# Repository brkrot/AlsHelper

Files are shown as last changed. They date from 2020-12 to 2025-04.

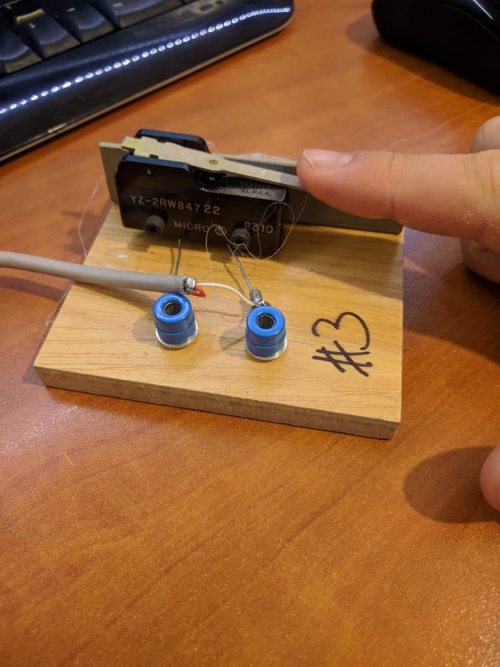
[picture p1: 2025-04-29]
Documents/צילומי מערכת/חיישן מורס.jpeg

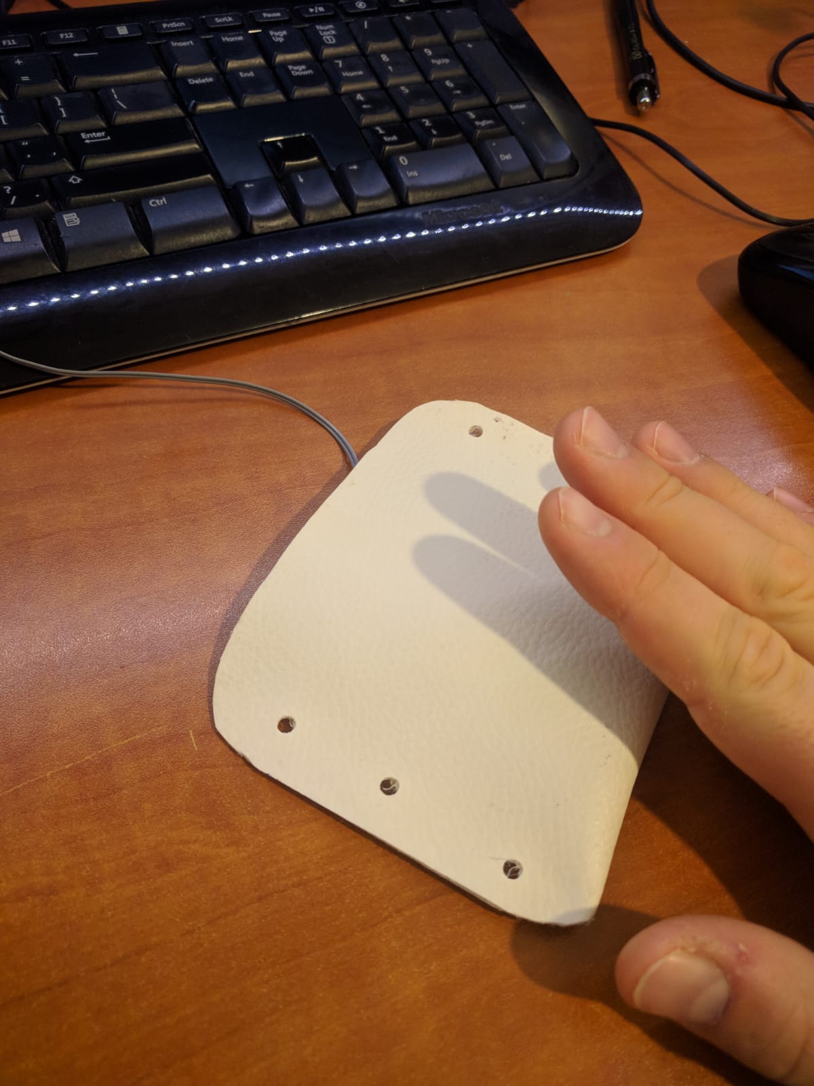
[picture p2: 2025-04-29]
Documents/צילומי מערכת/חיישן כפתור לחיצה רכה 2.jpeg

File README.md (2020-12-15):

# Milbat Project



1.	תקציר
פרויקט זה עוסק ביצירת פתרונות להקלה בחיי היומיום של בעלי מוגבלויות פיזיולוגיות באמצעות עזרים טכנולוגיים.
הרעיון של הפרויקט נובע מרצון משותף להציע פתרונות מסוג זה בשיתוף עם עמותת "מילב"ת" המתעסקת ללא מטרת רווח בסיוע טכנולוגי לאותו קהל.
במהלך הפרויקט פתחנו שתי מערכות:

•	מערכת ניתוח היכולות הפיזיולוגיות:
מטרתה היא לנתח ולמדוד, בעזרת חיישנים מתאימים, את יכולותיו הפיזיולוגיות של אדם עם מוגבלויות כדי שנוכל, בעזרת חיישנים אלו ליצור ממשק עזר מותאם אישית בעבורו. מערכת זו מופעלת ע"י קלינאית תקשורת של העמותה.
•	מערכת עזר מותאמת אישית:
המערכת מבוססת על מיקרו-מעבד מסוג Arduino. המערכת כוללת את אביזר החישה המתאים ביותר כפי שעלה מהניתוח הפיזיולוגי שבחלק הקודם והיא מותאמת אישית למטופל כך שתענה לצרכיו השונים להפעלת מכשירי IoT(התקני בית חכם) העונים לדרישות האדם עם המוגבלות (למשל הדלקה וכיבוי של מזגן, הדלקה וכיבוי של האור , הזעקת עזרה ע"י לחצן מצוקה וכו' ...)

בנוסף יצרנו גם אפליקציה המתאימה למכשירים מסוג Android שעובדת עם מערכות אלו.
האפליקציה שיצרנו מתממשקת למערכת ניתוח היכולות ועוזרת לנו בחיווי נוח וקל של יכולותיו הפיזיות של המטופל
באפליקציה זו יצרנו גם מחולל מערכת אישית. באמצעות ממשק פשוט ונוח ניתן ליצור קוד תכנותי עבור מערכת העזר, כך שניתן בקלות ליצור מערכת מותאמת אישית לכל מטופל.
בנוסף האפליקציה יכולה לתפקד יחד עם מערכת העזר על מנת לבצע פעולות תקשורתיות כגון שליחת SMS או התקשרות למספר טלפון/פלאפון.
* [ProjectVideos] - User Guide for the app and usage demonstrations
 [ProjectVideos]: https://www.youtube.com/playlist?list=PLXXLm4EyRK1NrguGM9qZ6Np-806uYKIgE

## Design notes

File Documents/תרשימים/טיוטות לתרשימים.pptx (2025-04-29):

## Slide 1

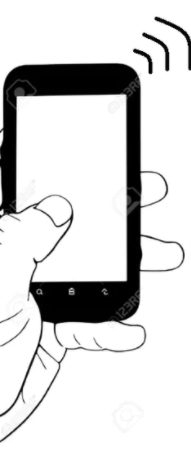
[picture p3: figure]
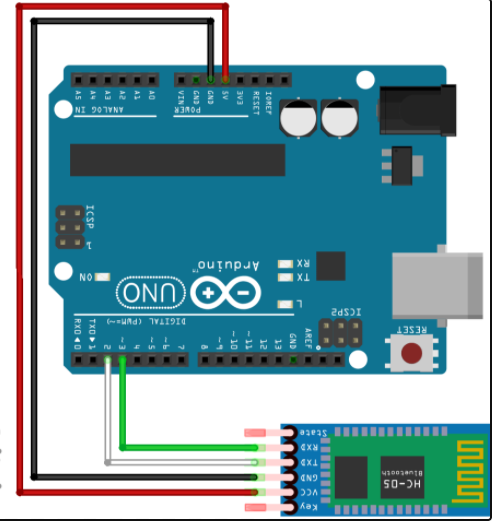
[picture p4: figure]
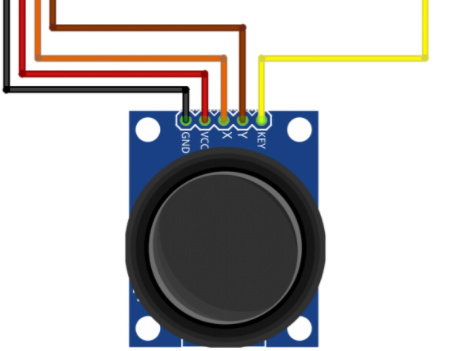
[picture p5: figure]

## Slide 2

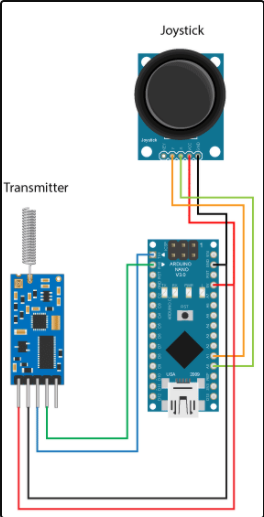
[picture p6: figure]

ג'ויסטיק/*חיישן אחר

צד הארדואינו | ג'ויסטיק/בלוטוס
A1 | VR-y
A0 | VR-x
5V | 5V
GND | GND
Pin3 | RXD
Pin2 | TXD

בלוטוס

אפליקציה

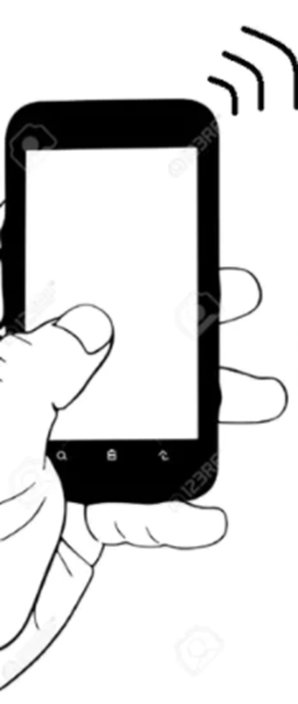
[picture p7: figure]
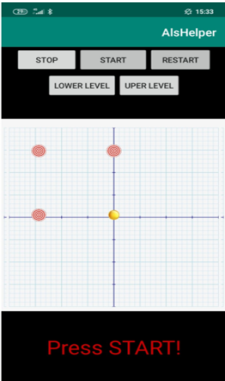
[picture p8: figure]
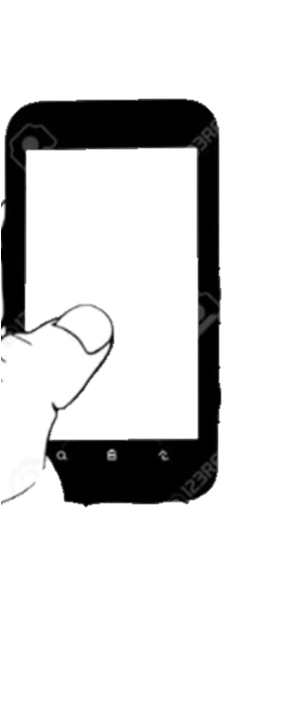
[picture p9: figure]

*זוהי דוגמא לחיבור חיישן בודד – בפועל חיברנו מס' רב של חיישנים כפי שיפורט להלןב

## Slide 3

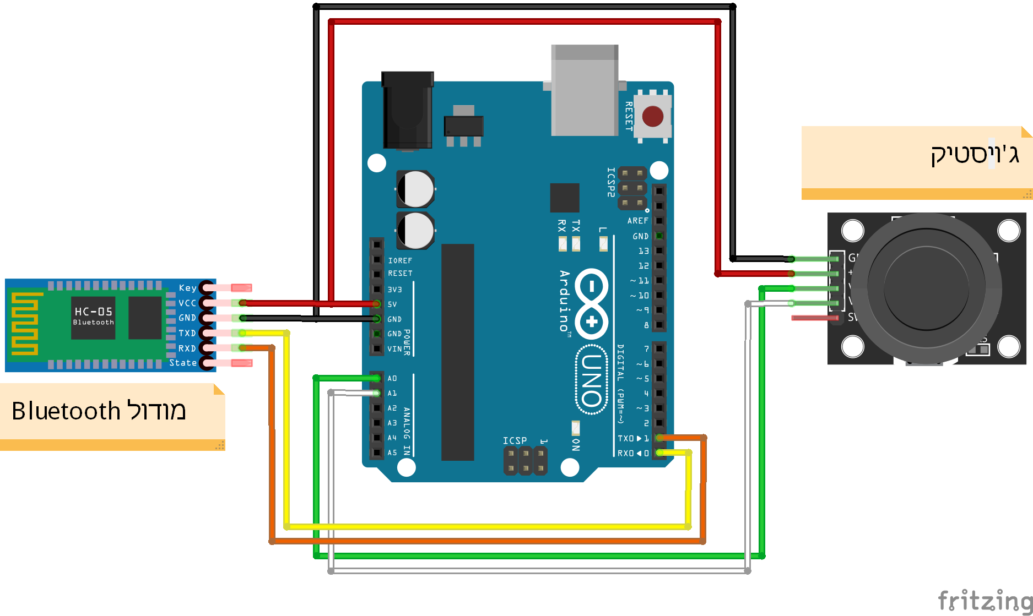
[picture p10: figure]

צבע החוט | החיבור על הלוח | ג'ויסטיק/Bluetooth
לבן | A1 | VR-y
ירוק | A0 | VR-x
אדום | 5V | 5V
שחור | GND | GND
צהוב | Pin1/Tx | RXD
כתום | Pin0/Rx | TXD

זוהי דוגמא לחיבור חיישן בודד – בפועל חיברנו מס' רב של חיישנים כפי שיפורט להלן.

אפליקציה

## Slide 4

מודול Bluetooth המחובר לארדואינו

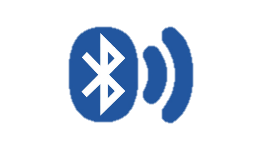
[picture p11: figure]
תוצאת תמונה עבור ‪bluet logo png‬‏

מתאם Bluetooth
במכשיר האנדרואיד

מיקרו בקר-ארדואינו

חיישן

אפליקציית האבחון

"מבחן" עם מסך חיווי

מחולל הקוד

המלצות
לקלינאית

שמירת המידע מן המבחן

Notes: בלוקים מערכת ניתוח

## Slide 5

מחולל הקוד

המלצות
לקלינאית

שמירת המידע מן המבחן

בחירת חיישן ע"פ המלצות

בחירת אופן תפעול החיישן הספציפי

בחירת פעולה עבור כ"א ממצבי החיישן

צריבה על מערכת עזר ריקה/מחודשת

שליחה למחשב

יצירת קובץ עם קוד תכנותי מותאם אישית

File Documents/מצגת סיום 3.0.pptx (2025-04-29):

## פרויקט מילב"ת

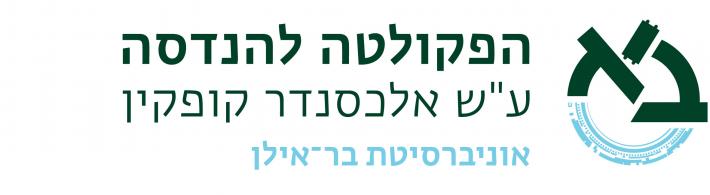
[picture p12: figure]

מערך IoT לאנשים עם מוגבלויות
פרויקט שנה ד'
דבי טברסקי וברק רוט

## הרקע לפרויקט

- קהל היעד – אנשים בעלי מוגבלויות עם אופי שיתוקי
- עמותת מילב"ת
- סיפורים אישיים של מטופלים
- הדרישות לפיתוח מוצר

## חלקי הפרויקט

- חלק 1- מערכת ניתוח היכולות הפיזיולוגיות
- חלק 2- מחולל קוד אישי
- חלק 3 – מערכת העזר

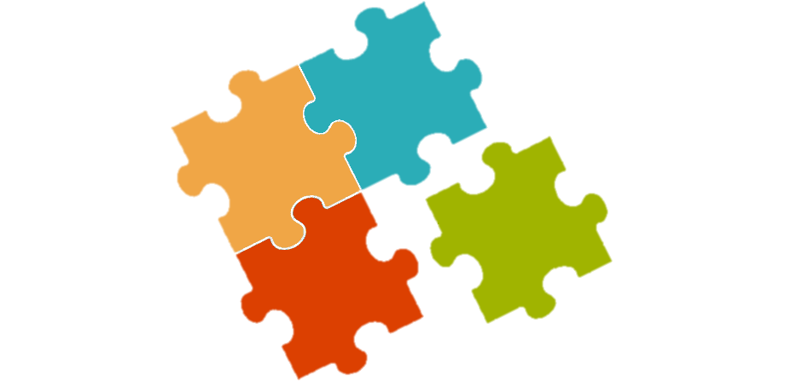
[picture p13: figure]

## הקשר בין המערכות השונות

- בפרויקט זה יש אפליקציה אחת ושני סוגים שונים של מערכות פיזיות.
- האחת, מערכת ניתוח יכולות. יש אחת כזו והיא זו שייכת לעמותת מילב"ת והיא מופעלת ע"י קלינאית התקשורת בזמן ניתוח היכולות.
- הסוג השני הוא מערכת עזר. הרעיון הוא שבעמותה יהיו כ-10 מערכות כאלו כך שבעת הצורך יוכלו בעמותה להתאים את כל המערכת לצרכי המטופל ולתת לו אותה לביתו
- האפליקציה נועדה בעיקר עבור מערכת ניתוח היכולות ובהמשך עבור מחולל הקוד האישי, אך היא רלוונטית גם עבור מערכת העזר.

## אביזרי קלט

- אביזרי הקלט מתחברים למערכת ניתוח יכולות ובהמשך אביזר בודד מחובר למערכת העזר האישית.
כל אביזר קלט מורכב מכמה חלקים:
- חיישן אלקטרוני
- התקן פלסטיק/גומי/אחר לצורך אחיזה נוחה ו/או חיבור על גוף המשתמש.
- חלקים נוספים הגורמים לתגובת החיישן להיות אפקטיבית (למשל מגנט בחיישן גבה)

## חלק 1 מערכת ניתוח יכולות

## חלק 1 - מערכת ניתוח יכולות

- הסבר על מטרת המערכת
- נועדה לתפעול ע"י קלינאית התקשורת של עמותת מילב"ת.
- פיתחנו אפליקציה ייעודית לצורך ניתוח היכולות
- המטופל עובר "מבחנים" בכל סוגי החיישנים.
- חיווי ויזואלי של קלט החיישן על גבי המסך של הפלאפון/ הטאבלט).
- לאחר ה"מבחנים" בכל החיישנים, האפליקציה תיתן את תוצאות המבחנים עבור כל חיישן.

## חלק 1 - מערכת ניתוח יכולות

מבנה כללי של המערכת

חיישן 3

חיישן 1

חיישן 2

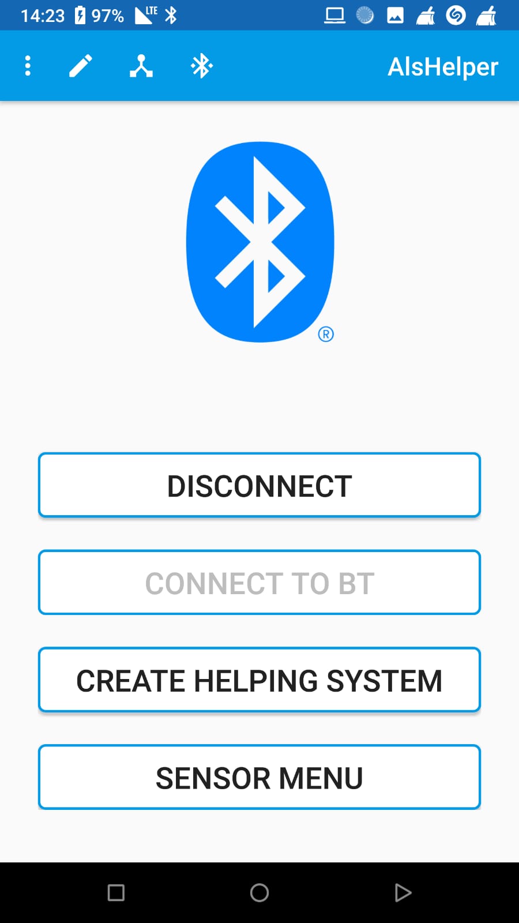
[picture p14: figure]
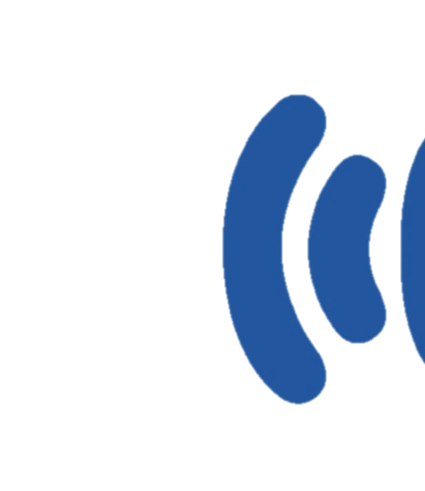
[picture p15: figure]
תוצאת תמונה עבור ‪bluet logo png‬‏
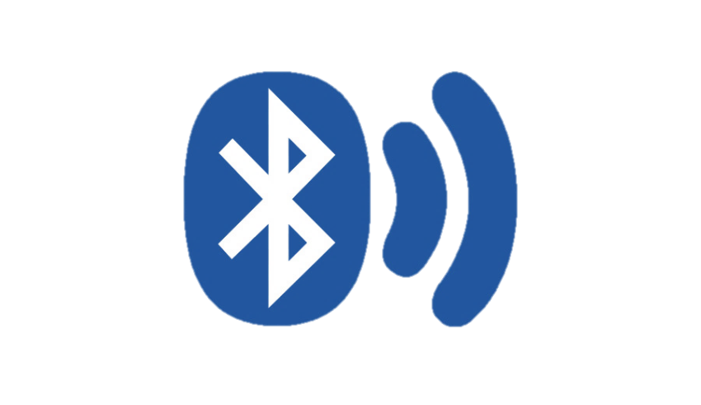
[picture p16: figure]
תוצאת תמונה עבור ‪bluet logo png‬‏
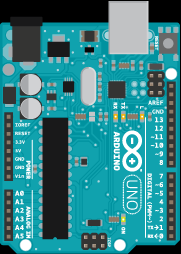
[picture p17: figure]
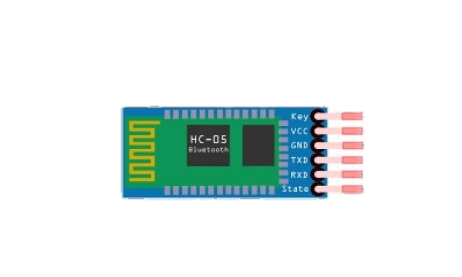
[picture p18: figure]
תוצאת תמונה עבור ‪hc 05 bluetooth clipart png‬‏

## חלק 1 - מערכת ניתוח יכולות

דיאגרמה תהליכית

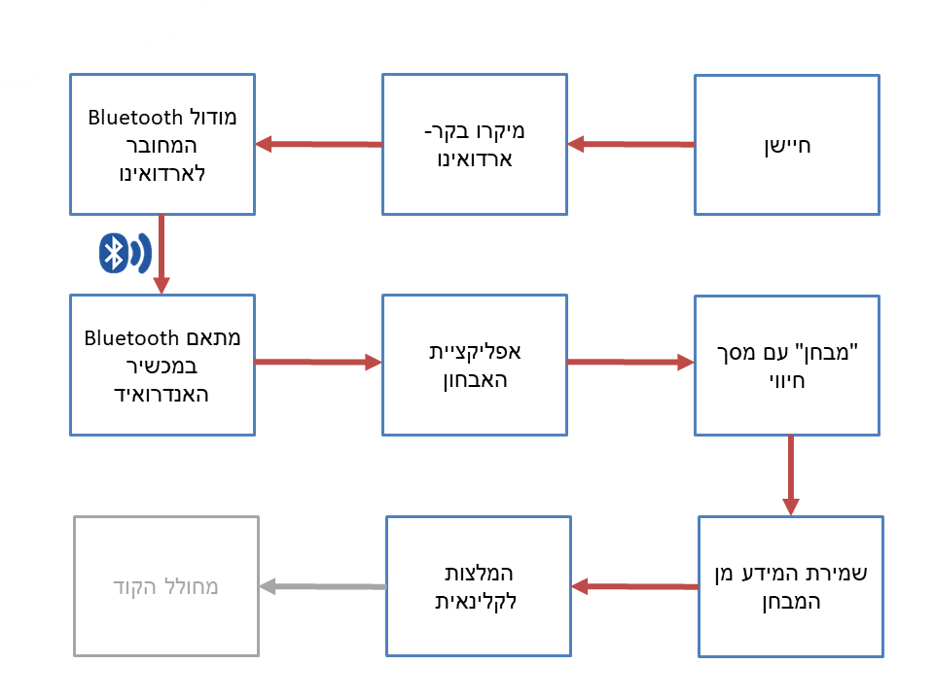
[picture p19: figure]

## סרטוני הדרכה לאפליקציה

לחץ על הסמל למעבר לסרטוני ההדרכה:

חלק 1 - מערכת ניתוח יכולות

## דיאגרמת חיבורים מפורטת - עם ג'ויסטיק

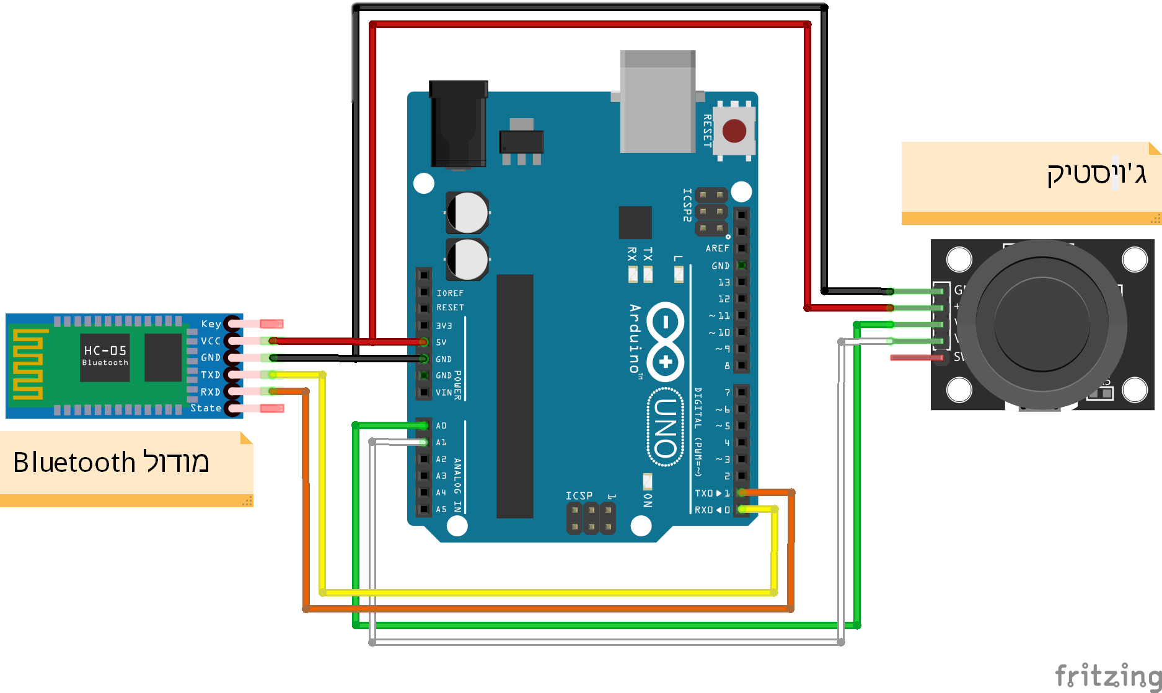
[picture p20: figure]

אפליקציה


צבע החוט | החיבור על הלוח | ג'ויסטיק/Bluetooth
לבן | A1 | VR-y
ירוק | A0 | VR-x
אדום | 5V | 5V
שחור | GND | GND
צהוב | Pin1/Tx | RXD
כתום | Pin0/Rx | TXD

חלק 1 - מערכת ניתוח יכולות

## חלק 2 מחולל קוד אישי

## מחולל קוד אישי

- כדי לגשר בין מערכת הניתוח ובין מערכת העזר יצרנו באפליקציה מחולל קוד אישי.
- בעזרת המחולל ניתן ליצור מערכת מותאמת אישית עבור כל מטופל בצורה פשוטה ונוחה.
- תהליך יצירה פשוט כך שגם מי שאינו מבין במחשבים יוכל ליצור מערכת עבור מטופל

חלק 2 - מחולל קוד אישי

## שלבי הביצוע

- הצגת מסך סיכום התוצאות
- בחירת חיישן ע"פ שיקול הקלינאית בשקלול עם התוצאות
- בחירת פעולות מוצא עבור החיישן
- שליחת הקוד למחשב
- "צריבת" הקוד על גבי מערכת עזר

חלק 2 - מחולל קוד אישי

## דיאגרמה תהליכית של השלבים

חלק 2 - מחולל קוד אישי

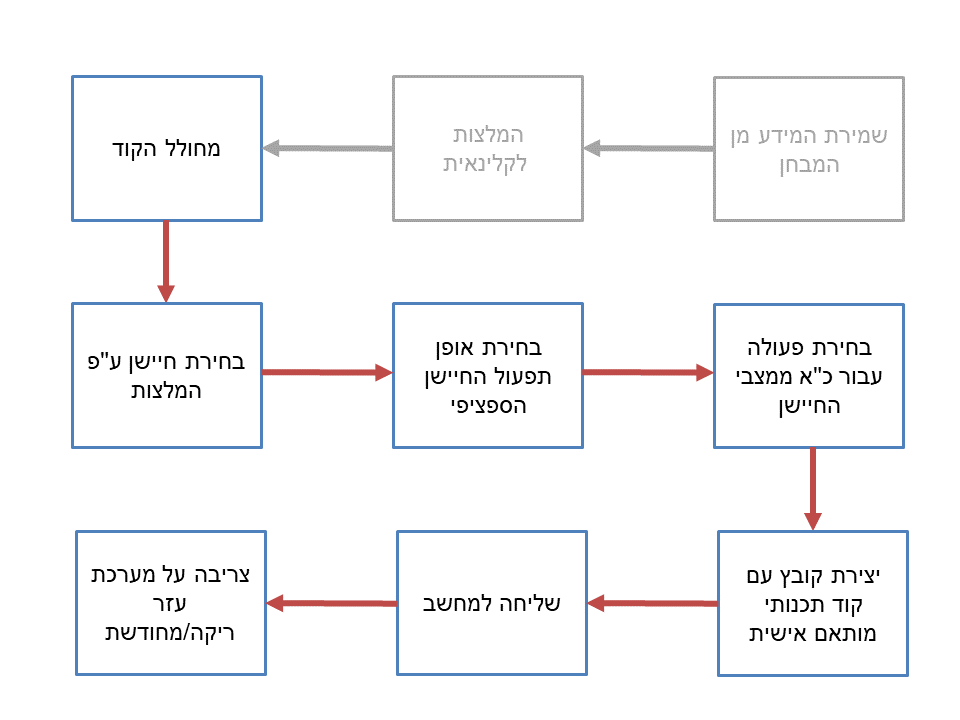
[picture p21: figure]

## סרטוני הדרכה למחולל המערכת האישית

לחץ על הסמל למעבר לסרטוני ההדרכה:

חלק 2 - מחולל קוד אישי

## חלק 3 מערכת העזר האישית

## מערכת העזר האישית

- מערכת עזר מותאמת אישית:
- המערכת מבוססת על מיקרו-מעבד מסוג Arduino.
- המערכת כוללת את אביזר החישה המתאים ביותר כפי שעלה מהניתוח הפיזיולוגי
- מותאמת אישית למטופל כך שתענה לצרכיו השונים
- דוגמאות - מזגן/אור /טלפון/SMS וכו'

חלק 3 - מערכת העזר האישית

## מבנה פשטני של מערכת העזר

חלק 3 - מערכת העזר האישית

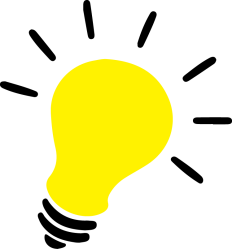
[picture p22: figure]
תוצאת תמונה עבור ‪bulb clipart png‬‏
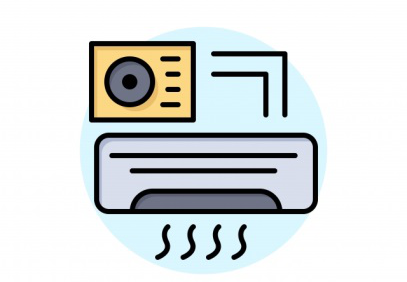
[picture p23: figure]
תוצאת תמונה עבור ‪aircon remote clipart png‬‏
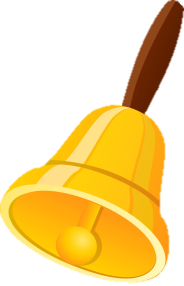
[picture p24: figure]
תוצאת תמונה עבור ‪bell clipart png‬‏

התקן קלט שנבחר בתהליך האבחון

Input

מארז מערכת העזר

Output

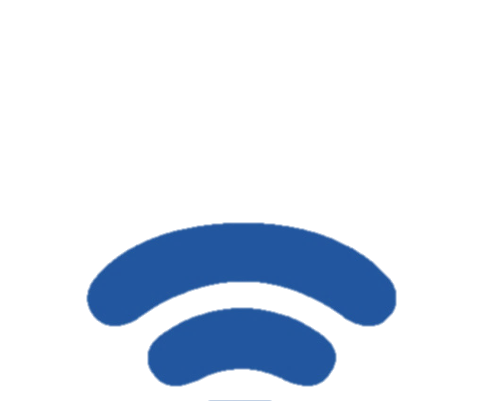
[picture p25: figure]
תוצאת תמונה עבור ‪bluet logo png‬‏

## חיבורים שונים אפשריים לחיישנים

חלק 3 - מערכת העזר האישית

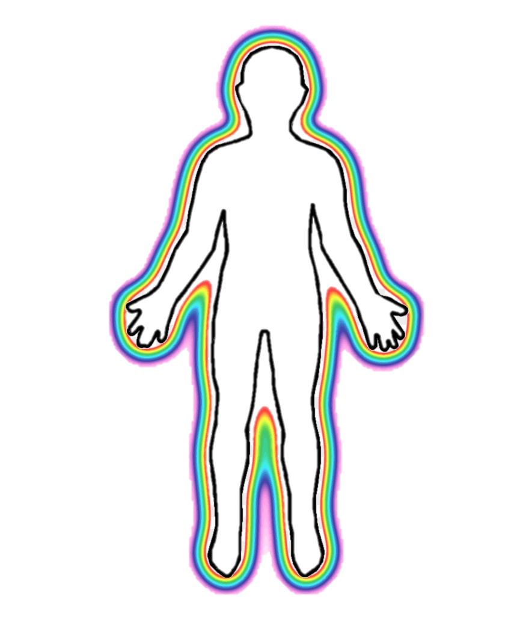
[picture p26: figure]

1

2

תוצאת תמונה עבור ‪aircon remote clipart png‬‏

מארז מערכת העזר

כל הכוכבים מייצגים מקומות בהם ניתן למקם אביזרי קלט-חיישנים

3

4

## דיאגרמת חיבורים מפורטת

חלק 3 - מערכת העזר האישית


מערכת העזר מחולקת לשלושה חלקים.
החלק השחור הוא החלק הנמצא בתוך המארז.
החלק הירוק הוא מתאם התאורה.
החלק האדום הוא החיישן הנבחר, ובמקרה הזה, הג'ויסטיק..

## סרטוני הדרכה למערכת ההתקשרות בעזרת מערכת העזר

לחץ על הסמל למעבר לסרטוני ההדרכה:

חלק 2 - מחולל קוד אישי

Sms Vector SVG Icon - PNG Repo Free PNG Icons
Call PNG Images | Vector and PSD Files | Free Download on Pngtree

## סרטוני הדגמה של תפעול מערכת העזר

לחץ על הסמל למעבר לסרטוני ההדרכה:

חלק 2 - מחולל קוד אישי

## סיכום ומסקנות

- עמדנו בדרישות הפרויקט
- דאגנו לפתח מערכת שנותנת מענה הן מבחינת הקלט והן מבחינת פעולת המוצא לכל אדם עם מוגבלות עם אפשרות התאמה אישית.
- תפעול כלל המערכות הוא קל ונוח וזמין.
יתרונות
- המערכת זולה מבחינה כספית
- ניתן לשדרג אותה יחסית בקלות
חסרונות:
שדרוג צריך להיעשות ע"י מומחה ולא ע"י כל אדם

חלק 2 - מחולל קוד אישי

## פיתוח עתידי

- שיפור בעזרת משוב משתמשים(קלינאית, מטופלים)
- קישוריות טובה יותר לIoT
- מעבר למיקרו בקר מסוג Esp 32
(מהיר יותר, זול יותר, קטן יותר, כולל רכיבי Bluetooth וגם Wi-Fi )
- שדרוג פיזי של המארזים
- שדרוג אפליקציה + הוספת ייעוד:
מערכת אימון - משחק שיחליף את חלק מן ה"מבחנים"

חלק 2 - מחולל קוד אישי

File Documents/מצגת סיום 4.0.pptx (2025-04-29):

## פרויקט מילב"ת


מערך IoT לאנשים עם מוגבלויות
פרויקט שנה ד'
דבי טברסקי וברק רוט
מנחים: ד"ר ססיל יחזקאל, ד"ר אברהם שלי

## הרקע לפרויקט

- קהל היעד – אנשים בעלי מוגבלויות עם אופי שיתוקי
- עמותת מילב"ת
- סיפורים אישיים של מטופלים
- הדרישות לפיתוח מוצר

## חלקי הפרויקט

- חלק 1- מערכת ניתוח היכולות הפיזיולוגיות
- חלק 2- מחולל קוד אישי
- חלק 3 – מערכת העזר


## הקשר בין המערכות השונות

- בפרויקט זה פיתחנו אפליקציה אחת עבור שני סוגים שונים של מערכות פיזיות.
- מערכת ניתוח יכולות. מופעלת ע"י קלינאית התקשורת הנמצאת בעמותת "מילב"ת" לצורך קליטה וניתוח היכולות הפיזית של מטופלים.
- מערכת עזר. הרעיון הוא שבעמותה יהיו כ-10 מערכות כאלו כך שבעת הצורך יוכלו בעמותה להתאים את כל המערכת לצרכי המטופל ולתת לו אותה לביתו
- האפליקציה נועדה בעיקר עבור מערכת ניתוח היכולות ובהמשך עבור מחולל הקוד האישי, אך היא רלוונטית גם עבור מערכת העזר.

## אביזרי קלט

- אביזרי הקלט מתחברים למערכת ניתוח יכולות ובהמשך אביזר בודד מחובר למערכת העזר האישית.
כל אביזר קלט מורכב מכמה חלקים:
- חיישן אלקטרוני
- התקן פלסטיק/גומי/אחר לצורך אחיזה נוחה ו/או חיבור על גוף המשתמש.
- חלקים נוספים הגורמים לתגובת החיישן להיות אפקטיבית (למשל מגנט בחיישן גבה)


## חלק 1 מערכת ניתוח יכולות

## חלק 1 - מערכת ניתוח יכולות

- הסבר על מטרת המערכת
- נועדה לתפעול ע"י קלינאית התקשורת של עמותת מילב"ת.
- פיתחנו אפליקציה ייעודית לצורך ניתוח היכולות
- המטופל עובר "מבחנים" בכל סוגי החיישנים.
- חיווי ויזואלי של קלט החיישן על גבי המסך של הפלאפון/ הטאבלט).
- לאחר ה"מבחנים" בכל החיישנים, האפליקציה תיתן את תוצאות המבחנים עבור כל חיישן.

## חלק 1 - מערכת ניתוח יכולות

מבנה כללי של המערכת

חיישן 3

חיישן 1

חיישן 2


מיקרו בקר + מודול בלוטות'

תוצאת תמונה עבור ‪bluet logo png‬‏
תוצאת תמונה עבור ‪bluet logo png‬‏
תוצאת תמונה עבור ‪hc 05 bluetooth clipart png‬‏

## חלק 1 - מערכת ניתוח יכולות

דיאגרמה תהליכית


## סרטוני הדרכה לאפליקציה

לחץ על הסמל למעבר לסרטוני ההדרכה:

חלק 1 - מערכת ניתוח יכולות

## דיאגרמת חיבורים מפורטת - עם ג'ויסטיק


אפליקציה


צבע החוט | החיבור על הלוח | ג'ויסטיק/Bluetooth
לבן | A1 | VR-y
ירוק | A0 | VR-x
אדום | 5V | 5V
שחור | GND | GND
כתום | Pin1/Tx | RXD
צהוב | Pin0/Rx | TXD

חלק 1 - מערכת ניתוח יכולות

## חלק 2 מחולל קוד אישי

## מחולל קוד אישי

- כדי לגשר בין מערכת הניתוח ובין מערכת העזר יצרנו באפליקציה מחולל קוד אישי.
- בעזרת המחולל ניתן ליצור מערכת מותאמת אישית עבור כל מטופל בצורה פשוטה ונוחה.
- תהליך יצירה פשוט כך שגם מי שאינו מבין במחשבים יוכל ליצור מערכת עבור מטופל

חלק 2 - מחולל קוד אישי

## שלבי הביצוע

- הצגת מסך סיכום התוצאות
- בחירת חיישן ע"פ שיקול הקלינאית בשקלול עם התוצאות
- בחירת פעולות מוצא עבור החיישן
- שליחת הקוד למחשב
- "צריבת" הקוד על גבי מערכת עזר

חלק 2 - מחולל קוד אישי

## דיאגרמה תהליכית של השלבים

חלק 2 - מחולל קוד אישי


## סרטוני הדרכה למחולל המערכת האישית

לחץ על הסמל למעבר לסרטוני ההדרכה:

חלק 2 - מחולל קוד אישי

## חלק 3 מערכת העזר האישית

## מערכת העזר האישית

- מערכת עזר מותאמת אישית:
- המערכת מבוססת על מיקרו-מעבד מסוג Arduino.
- המערכת כוללת את אביזר החישה המתאים ביותר כפי שעלה מהניתוח הפיזיולוגי
- מותאמת אישית למטופל כך שתענה לצרכיו השונים
- דוגמאות - מזגן/אור /טלפון/SMS וכו'

חלק 3 - מערכת העזר האישית

## מבנה פשטני של מערכת העזר

חלק 3 - מערכת העזר האישית

תוצאת תמונה עבור ‪bulb clipart png‬‏
תוצאת תמונה עבור ‪aircon remote clipart png‬‏
תוצאת תמונה עבור ‪bell clipart png‬‏

התקן קלט שנבחר בתהליך האבחון

Input

מארז מערכת העזר

Output

תוצאת תמונה עבור ‪bluet logo png‬‏

## חיבורים שונים אפשריים לחיישנים

חלק 3 - מערכת העזר האישית


1

2

תוצאת תמונה עבור ‪aircon remote clipart png‬‏

מארז מערכת העזר

כל הכוכבים מייצגים מקומות בהם ניתן למקם אביזרי קלט-חיישנים

3

4

## דיאגרמת חיבורים מפורטת

חלק 3 - מערכת העזר האישית


מערכת העזר מחולקת לשלושה חלקים.
החלק השחור הוא החלק הנמצא בתוך המארז.
החלק הירוק הוא מתאם התאורה.
החלק האדום הוא החיישן הנבחר, ובמקרה הזה, הג'ויסטיק..

## סרטוני הדרכה למערכת ההתקשרות בעזרת מערכת העזר

לחץ על הסמל למעבר לסרטוני ההדרכה:

חלק 2 - מחולל קוד אישי

Sms Vector SVG Icon - PNG Repo Free PNG Icons
Call PNG Images | Vector and PSD Files | Free Download on Pngtree

## סרטוני הדגמה של תפעול מערכת העזר

לחץ על הסמל למעבר לסרטוני ההדרכה:

חלק 2 - מחולל קוד אישי

## סיכום ומסקנות

- עמדנו בדרישות הפרויקט
- דאגנו לפתח מערכת שנותנת מענה הן מבחינת הקלט והן מבחינת פעולת המוצא לכל אדם עם מוגבלות עם אפשרות התאמה אישית.
- תפעול כלל המערכות הוא קל ונוח וזמין.
יתרונות
- המערכת זולה מבחינה כספית
- ניתן לשדרג אותה יחסית בקלות
חסרונות:
שדרוג צריך להיעשות ע"י מומחה ולא ע"י כל אדם

חלק 2 - מחולל קוד אישי

## פיתוח עתידי

- שיפור בעזרת משוב משתמשים(קלינאית, מטופלים)
- קישוריות טובה יותר לIoT
- מעבר למיקרו בקר מסוג Esp 32
(מהיר יותר, זול יותר, קטן יותר, כולל רכיבי Bluetooth וגם Wi-Fi )
- שדרוג פיזי של המארזים
- שדרוג אפליקציה + הוספת ייעוד:
מערכת אימון - משחק שיחליף את חלק מן ה"מבחנים"

חלק 2 - מחולל קוד אישי

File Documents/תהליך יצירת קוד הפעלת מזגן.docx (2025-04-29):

1. תחיבורים
  a. לד משדר:

חיבור הטרנזיסטור
2N2222 :


https://en.wikipedia.org/wiki/2N2222

חיבור המעגל המלא יחד עם הטרנזיסטור:


את המתח 5V לקחתי מיציאת 5וולט של הארדואינו ובפעם אחרת לקחתי באופן מאולתר מבית הסוללות ע"י חיבור שני חוטים בקצוות הסוללות (4 סוללות סה"כ יצא לי ~6V)
הנגדים אצלי הם של 220 אום

  b. לד קליטה - BRM:

חיברתי את הלד הקולט ע"פ התרשים הבא:

רגלי הלד:

IR Receiver Stand-Alone Pinout Diagram

אופן החיבור: הכחול בפין מס 11(לא 7)

Arduino IR Remote Receiver - Stand-Alone IR Receiver Wiring Diagram

2. קודי ארדואינו
  a. קריאת אות אינפרא אדום מהשלט:

השתמשתי בספרייה הידועה IRremote
ושם השתמשתי בקובץ - IRrecvDumpV2


כשהפעלתי קובץ זה קיבלתי את הפלט הנ"ל עבור לחיצה בודדת של שלט המזגן(הדלקה על קור ב24 מעלות):

START F:\Documents\Arduino\libraries\IRremote\examples\IRrecvDumpV2\IRrecvDumpV2.ino from Sep 2 2020

Ready to receive IR signals at pin 11

Encoding : NEC

Code : 0x1098D008 (32 bits)

Timing[83]:

+8900, -4400 + 550, - 550 + 550, - 500 + 600, - 500

+ 550, -1600 + 600, - 500 + 550, - 550 + 550, - 500

+ 550, - 550 + 550, -1600 + 550, - 550 + 550, - 500

+ 600, -1600 + 550, -1600 + 550, - 550 + 550, - 500

+ 600, - 500 + 550, -1600 + 550, -1650 + 550, - 500

+ 550, -1600 + 600, - 500 + 550, - 550 + 550, - 500

+ 600, - 500 + 550, - 550 + 550, - 500 + 600, - 500

+ 550, - 550 + 550, -1600 + 550, - 550 + 550, - 500

+ 600, - 500 + 550, - 550 + 550, - 500 + 550, -1650

+ 550, -1600 + 550, - 500 + 600, - 500 + 550, - 550

+ 550, - 500 + 600

Pronto Hex: 0000 006D 002A 0000 0156 00A9 0015 0015 0015 0013 0017 0013 0015 003E 0017 0013 0015 0015 0015 0013 0015 0015 0015 003E 0015 0015 0015 0013 0017 003E 0015 003E 0015 0015 0015 0013 0017 0013 0015 003E 0015 003F 0015 0013 0015 003E 0017 0013 0015 0015 0015 0013 0017 0013 0015 0015 0015 0013 0017 0013 0015 0015 0015 003E 0015 0015 0015 0013 0017 0013 0015 0015 0015 0013 0015 003F 0015 003E 0015 0013 0017 0013 0015 0015 0015 0013 0017 0806

unsigned int rawData[83] = {8900,4400, 550,550, 550,500, 600,500, 550,1600, 600,500, 550,550, 550,500, 550,550, 550,1600, 550,550, 550,500, 600,1600, 550,1600, 550,550, 550,500, 600,500, 550,1600, 550,1650, 550,500, 550,1600, 600,500, 550,550, 550,500, 600,500, 550,550, 550,500, 600,500, 550,550, 550,1600, 550,550, 550,500, 600,500, 550,550, 550,500, 550,1650, 550,1600, 550,500, 600,500, 550,550, 550,500, 600}; // NEC 1098D008

unsigned int data = 0x1098D008;

השורה המודגשת היא מה שמעניין אותנו ואותה הכנסתי לקוד השידור

  b. קוד ארדואינו - שידר האות המוקלט לצורך הפעלת המזגן:

השתמשתי בספרייה הידועה IRremote
ושם השתמשתי בקובץ – IrsendRawDemo

בקובץ זה השתמשתי רק בחלק הראשון ובו הדבקתי את קוד האינפרא אדום

יכולת תכנות – שמירת הקודים בזיכרון:
אני השתמשתי בספרייה שנקרא EEPROM שנותנת גישה אל הזיכרון ויכולת לכתוב שם באופן קבוע גם אחרי ריסט
גודל הזיכרון הוא 1 קילו בייט

הכתיבה היא בשתי צורות
read write שכותבים אל בייט בודד
וput get שהם ככל הנראה חדשים יותר לפי מה שקראתי באחד המקומות והם מאפשרים כתיבה ליותר מבייט אחד (כלומר ניתן לכתוב מספרים בגדול של יותר

מ 255=2^8 .

כתבתי שתי פונקציות שיודעות לקרוא מערך מהזיכרון ולכתוב אחד לזיכרון
יש ספרייה מורחבת שעושה את הדברים האלו אבל העדפתי לממש כי המימוש היה לא ככ מסובך וכמובן תמיד עדיף להבין מה אתה עושה ולא להסתמך..
https://github.com/thijse/Arduino-EEPROMEx זאת הכתובת של הספרייה המורחבת

הקובץ האחרון שכתבתי , זה שהצליח להפעיל אצלי את המזגן זה הקובץ

Aux_system_programmble_AC_v1.0_dirty_code_

זה קובץ שמשלב את כל הקודים שראית במסמך זה
יש שם בעיות ודברים לא פתורים עד הסוף אבל העיקר שהוא עובד.

בעיות שיש כרגע בקוד הנוכחי:

- בלאגן
- יש הרבה פונקציות שנלקחו מהקוד של הרסיבר (הקוד השני במסמך זה)
- לא עובד על כל המזגנים
- ניתן לתכנת פעם אחת, אחר כך זה לא עובד
- הפעלה ארוכה מידי של הקוד כאשר לוחצים ימינה

יש מצב שכדאי לכתוב ממחדש את הקוד הזה בצורה מסודרת

כתבתי אותו מהר כי מיהרתי לצאת ולכן הוא לא מסודר מספיק בעיני

~~משהו חשוב~~
~~בעיקרון אפשר להשתמש בקבצים חיצוניים וכך להפוך את הקוד למודולרי~~
~~למשל~~ ~~–~~ ~~יהיה קוד חיצוני שיהיה אחראי לקלוט את אות המזגן וכך אפשר לעבוד בצורה נוחה ומודולרית יותר~~
~~מוטיבציה נוספת לכך~~ ~~–~~ ~~יש לנו צורך ליצור תוכנת אנדרואיד שכותבת קודי ארדואינו.~~
~~אם נצליח לעבוד עם מספר קבצים יהיה לנו יותר קל להרכיב את הפאזל של הקוד הסופי(דבר איתי אם זה לא מספיק ברור למה הכוונה)~~

יש פה כמה קישורים שעזרו לי:

קישור שמסביר איך להתקין סביבת עבודה לארדואינו בתוך ויזואל סטודיו:

https://maker.pro/arduino/tutorial/how-to-use-visual-studio-for-arduino-development

EEPROM

https://roboticsbackend.com/arduino-store-array-into-eeprom/#Writing_int_array_into_EEPROM

https://roboticsbackend.com/arduino-store-int-into-eeprom/

לינקים כללים למדריכי ארדואינו שהמליצו עליהם בקבוצה בפייסבוק:

אחד מהם זה מדריך לארדואינו והשני זה מדריך לכל האלקטרוניקה שמסביב

https://www.youtube.com/playlist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

https://www.youtube.com/playlist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

עוד קישור שיכול להיות שיהיה רלוונטי לנו, משהו לגבי מזדן תדיראן:

https://pastebin.com/hGS2dp1C?fbclid=IwAR2L-4BS2ILfgeg7TMHHI9Gny1b-RQLmAtBrrW3DvM7_63bSjEvXRS41w5E

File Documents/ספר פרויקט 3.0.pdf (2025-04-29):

בס"ד

# פיתוח מערך IoT לאנשים עם מוגבלויות

### פרויקט שנה ד'

# דבי טברסקי 203528021 ברק רוט 203679725

# מנחים :

# ד"ר ססיל יחזקאל

# דר אברהם שלי

# מנחה אקדמי: ד"ר אדי תימן

# תוכן עניינים

תוכן
תוכן עניינים 2 |
.1 תקציר3 |

### 2. הרקע לפרויקט4 |

2.1. קהל היעד 4 |
2.2. עמותת מילב"ת 5 |
.2.3 סיפור אישי של מטופלים5 |
.2.4 הדרישות לפיתוח מוצר 5 |
.3 שיקולים במענה לצורך 7 |
.3.1 מצבו ההתחלתי של המוצר 7 |
3.2. ההחלטה לגבי סביבת הפיתוח 7 |
.4 לב הפרויקט – הדרך לפתרון8 |
4.1. מערכת ניתוח היכולות 8 |

## .1 תקציר

פרויקט זה עוסק ביצירת פתרונות טכנולוגיים להקלה בחיי היומיום של בעלי מוגבלויות פיזיולוגיות. הפרויקט נעשה בשיתוף עם עמותת "מילב"ת" העוסקת בסיוע ומציאת פתרונות הנדסיים ו/או טכנולוגיים עבור בעלי מוגבלויות אלו )ללא מטרת רווח(.

במהלך הפרויקט פיתחנו שתי מערכות:
- מערכת ניתוח היכולות הפיזיולוגיות: מטרת המערכת היא לנתח ולמדוד, בעזרת חיישנים מתאימים, את יכולת המוטוריקה של המטופל ביחס לחיישנים הקיימים במערכת. בעזרת מידע זה, נוכל ליצור מערכת עזר מותאמת אישית המצריכה יכולות מוטוריות אלו. מערכת זו מופעלת ע"י קלינאית תקשורת של העמותה.
- מערכת עזר מותאמת אישית:
המערכת )מבוססת על מיקרו-מעבד מסוג Arduino )המערכת כוללת את החיישן המתאים ביותר כפי שעלה מהניתוח הפיזיולוגי של המערכת הראשונה. מערכת עזר זו מותאמת אישית למטופל כך שתענה לצרכיו השונים להפעלת מכשירי IoT( התקני בית חכם כגון הדלקה וכיבוי של מזגן, הדלקה וכיבוי של האור , הזעקת עזרה ע"י לחצן מצוקה וכו' ...(

בנוסף יצרנו גם אפליקציה המתאימה למכשירים מסוג Android אפליקציה זו עובדת עם שתי מערכות אלו.
האפליקציה שיצרנו מתממשקת למערכת ניתוח היכולות ועוזרת לנו בחיווי נוח וקל של יכולותיו הפיזיות של המטופל וכן אוספת את המידע מה -"מבחנים".

באפליקציה זו יצרנו גם מחולל קוד )ארדואינו( אישי. באמצעות ממשק פשוט ונוח ניתן ליצור קוד תכנותי עבור מערכת העזר, כך שניתן בקלות ליצור מערכת מותאמת אישית לכל מטופל.

בנוסף האפליקציה משמשת כחלק ממערכת העזר למטרת פעולות תקשורתיות כגון שליחת SMS או חיוג למספר טלפון/פלאפון.

## .2 הרקע לפרויקט

הבעיה, או ליתר דיוק, הקו שי שבו באנו לסייע בפרויקט זה, הוא חוסר היכולת בהתנהלות העצמאית של אנשים בעלי מוגבלויות פיזיות קשות ובמיוחד אלו שמתקשים לדבר )ולכן לא יכולים להשתמש בעוזרת קולית(. בפרט מדובר בהפעלת מכשירים חשמליים שונים הדורשים שימוש באצבעות. המערכת שלנו באה לתת מענה ולנסות לגשר על הפער הזה. המערכת מיועדת לאנשים משותקים ו / או חולי ALS במצב קשה. המערכת אמורה לאפשר למשתמש בה לבצע פעולות, שעבורו הם מורכבות ודורשות הפעלת חלקים רבים בגופו, בצורה פשוטה. פרויקט זה הוא בשיתוף עם עמותת מילב"ת. הקשר של הפקולטה להנדסה בבר אילן עם עמותת מילב"ת החל לפני מספר שנים ביוזמתה של ד"ר ססיל יחזקאל.

עמותת מילב"ת עוזרת, ללא מטרת רווח, לבעלי מוגבלויות בכלל התחומים. עד כה בעמותה כמעט לא ניתנו פתרונות העושים שימוש בטכנולוגיות חכמות. בפרויקט זה באנו לענות על חוסר בפתרון טכנולוגי, שלא היה קיים בעמותה עד כה. אחד הדברים שעוררו בנו מוטיבציה הוא סיפורו של אלחנן, המשותק מהצוואר ומטה שנתפרה בעבורו בעבר מערכת עזר שכזו. בעקבות המקרה של אלחנן הועלתה ה הצעה ליצור מערכת רחבה יותר שתתן מענה למקרים רבים יותר ותענה על טווח רחב של צרכים ויכולות פיזיולוגיות של המטופלים.

.2.1 קהל היעד
קהל היעד של המערכת שלנו הוא בעלי מוגבלויות עם אופי שיתוקי. המערכת שאנו מספקים מכוונת בעיקר לאנשים שמשותקים ברוב גופם ונותרו להם מספר פעולות ספורות שביכולתם לבצע )הזזה מעטה של האצבע/הזזת גבה וכיו"ב(

המקרים השכיחים ביותר של מצבים אלו הם המקרים של החולים בניוון שרירים.

ניוון שרירים )ALS-Sclerosis Lateral Amyotrophic ) היא מחלה שפוגעת בתאי עצב מוטוריים הנמצאים במוח ובחוט השדרה. תאים אלה מפעילים את כל שרירי הגוף, אך כתוצאה מהמחלה הם נהרסים והשרירים אינם מקבלים את המסרים להפעלתם והם מתנוונים ומאבדים את היכולת להתכווץ. אותם אלו החולים בשלב מתקדם של המחלה, חווים שיתוק בחלק גדול מגופם ובחלק מהמקרים קושי בדיבור או חוסר יכולת לדבר כלל.

המטרה שלנו בפרויקט זה היא יצירת מערכת שתיתן למטופל אפשרות לבצע פעולות יומיומיות הכרוכות בשימוש באמצעים אלקטרוניים על מנת להקל על חייו. מטרה נוספת היא לתת מצד אחד למטפל כלי שמאפשר לו לנצל את היכולות של המטופל ומצד שני לתת למטופל תחושה של מעט יותר "עצמאות" ,שכן ברמה הפסיכולוגית לא קל לאדם להיות נזקק בכל רגע ורגע לעזרה. המערכת שלנו נותנת לו, ולו במעט, שליטה על מספר פעולות שהוא יוכל לבצע בעצמו.

.2.2 עמותת מילב"ת
עמותת מילב"ת מעניקה ליווי וסיוע מקצועי לשיפור העצמאות של בעלי מוגבלויות, באמצעות טכנולוגיה מסייעת.

לאתר האינטרנט של עמותת מילב"ת (https://www.milbat.org.il/)

מילב"ת היא עמותה ציבורית ללא כוונת רווח, שפועלת בכל רחבי הארץ על מנת להעניק לאנשים עם ירידה בתפקוד את הזכות ואת האפשרות ליהנות מעצמאות מרבית באמצעות סביבה טכנולוגית מותאמת.
בעמותה צוות מומחים פרה רפואי ו600- מתנדבים שמשלבים בין ידע שיקומי ובין ידע טכנולוגי, ומעניקים מכלול שירותי ייעוץ, פיתוח, מידע והדרכה שמסייעים לאנשים עם מוגבלות בני כל הגילאים ולקשישים לשפר את התפקוד ואת איכות החיים.

### .2.3 סיפור אישי של מטופלים

במהלך השנים האחרונות עבדו ד"ר אברהם שלי וד"ר ססיל יחזקאל בשיתוף עם עמותת מילב"ת במטרה לתת פתרונות טכנולוגים עבור אנשים עם מוגבלויות פיזיות.

נוצרו תתי פרויקטים שונים בתחום זה כדי לענות על צרכים נקודתיים.

אחד מן המקרים בהם היה צורך שכזה הוא המקרה של אלחנן ,חבר של ד"ר אברהם שלי, אחד ממנחי הפרויקט. אלחנן לקה בשיתוק מהצוואר ומטה וצריך הנשמה מלאכותית באופן קבוע. שיתוק זה קרה לאחר ניתוח בעמוד השדרה. אומנם אלחנן מסוגל לשלוט על ראשו ולנשוף דרך עכבר נשיפה. אך היה לו צורך בהפעלת מכשירים נוספים. לפני שנתיים פותחו בפקולטה להנדסה בבר אילן ניסיונו ת להתאים לו שלט מסוג Joystick כדי שהוא יוכל להפעיל מזגן ותאורה במנורת צד על ידי תנועת הסנטר. בשילוב מערכת מסוג .ARDUINO

המקרה השני הוא הוא המקרה של דוד פ. שחלה בניוון שרירים והיה זקוק למערכת הזעקה/התרעה זמינה 24/7 במקרה של מצוקה. היכולת הפיזית היחידה שלו היא להזיז את עיניו ואת גבותיו.

המטרה הייתה לפתח עבורו חיישן לחיצה כדי לקרוא למטפל הסיעודי שלו. לאחר תקופה בוצע פרויקט בפקולטה להנדסה שיצר עבורו פתרון טכנולוגי. הפתרון היה בדמות לחצן המפעיל פעמון הקורא למטפל. הפרויקט התחיל בהתנדבות של הסטודנטים מהפקולטה להנדסה ) אלכס כץ ותומר לוקר( תחת הנחייתו של ד"ר אברהם שלי והם הצליחו לפתח את המערכת ולהרכיבה בבית של אותו המטופל.

### .2.4 הדרישות לפיתוח מוצר

בנקודה זו נולד בסיס הרעיון של פרויקט זה, בהתייעצות עם חוה קלינאית התקשורת של עמותה וכן עם מעיין, מעצבת מוצר שהתנדב ה בעמותה באותה העת, ה וצע ליצור מערכת עזר מודולרית, שתו תאם בקלות לכל מטופל, על פי יכולותיו וללא צורך בפיתוח חוזר הצורך משאבים וזמן.

בנוסף, כדי להתאים את המערכת ולמקסם את יכולותיה עבור כל מטופל, הוצע ליצור מערכת ניתוח יכולות פיזיולוגיות, שתתן יכולת פשוטה לקלינאית לאפיין את הצרכים והדרישות מהמערכת המודולרית בצורה הטובה ביותר.

בפרויקט זה, למדנו את צרכי המטופלים, אפיינו מערכת עזר מודולרית ומערכת ניתוח יכולות, למדנו מגוון תחומים טכנולוגים לצורך מימוש המוצר באופן אישי לכל מטופל. למעשה פיתחנו את המוצרים מקצה לקצה, מרמת התוכנה ועד לרמת ה חוטים וההלחמות.

## .3 שיקולים במענה לצורך

### .3.1 מצבו ההתחלתי של המוצר

כאשר התחלנו לפתח פרויקט זה, הייתה ברשותנו מערכת בסיסית שהייתה קיימת מכבר. הייתה שם אפליקציה בסיסית שאפשרה לראות גרף המציג את המידע שמגיע מן החיישנים, לאורך זמן ה"מבחן". בין אם מדובר במידע אנאלוגי או דיגיטלי. בנוסף הייתה באפליקציה אפשרות לשמור את הנתונים. שקלנו רבות האם כדאי לנו לשכלל את מה שעשו לפנינו או להתחיל משהו משלנו.

היו מספר בעיות עם המימוש הקודם:

- האפליקציה נכתבה בInventor App MIT ,זוהי פלטפורמה נוחה לכתיבת אפליקציות פשוטות ללא צורך בידע ממשי בתכנות. הבעיה עם הפלטפורמה הזאת היא חוסר גמישות. מרחב הפעולה שיש שם הוא מוגבל. ידענו שבעתיד נרצה להוסיף שינויים מגוונים שפלטפורמה זו לא מסוגלת להציע.
- המערכת הפיזית הייתה מחוברת בצורה לא נוחה ולא הציגה שום מימוש נוח לחיבור פיזי על הנבדק כך שנוכל לבחון את המערכת בפועל.
- צורת העבודה )קבלת גרף( לא נותנת מידע מספיק לקלינאית התקשורת שאמורה להבין מהו החיישן המתאים ביותר. נדרשה הכוונה ברורה יותר כגון ציונים/מספרים/סקאלה המבטא ים את מידת ה התאמה של כל חיישן לכל מטופל.

### .3.2 ההחלטה לגבי סביבת הפיתוח

מכל הסיבות המנויות לעיל החלטנו לפנות אל עבר כתיבת אפליקציה משלנו בשפת Java ע"י שימוש בסביבת הפיתוח- Studio Android סביבת התכנות הרשמית לאפליקציות אנדרואיד. זו הייתה הדרך הארוכה שהיא קצרה. המון השקעה עכשיו כדי שאנו, ואלו שאחרינו יוכלו לצמוח מתוך הבסיס הזה ולשדרג את האפליקציה.

במקביל בנינו את המערכות האלקטרוניות שלנו בצורה נוחה ומודולרית כך שיענו על הצרכים של המשתמשים, קלינאית התקשורת, המפתחים הבאים אחרינו וכל הנוגעים בדבר, באופן מיטבי.

## .4 לב הפרויקט – הדרך לפתרון

בפרק זה נעסוק בפירוט החלקים השונים של הפרויקט, בקשרים ביניהם ובפרטים השונים, תפעוליים וטכנולוגיים. המוצר שפיתחנו משלב סוגים שונים של מער כות סביב פלטפורמה של מיקרו בקר מסוג Arduino.

.4.1 מערכת ניתוח היכולות
"מערכת ניתוח יכולות פיזיולוגיות")תרשים 1( נועדה לתפעול ע"י קלינאית התקשורת של עמותת מילב"ת.

המערכת מכילה מספר רב של חיישנים, לדוגמה - כפתור פשוט, חיישן מרחק, חיישן גבה או ג'ויסטיק וכו' .)תמונות נוספות מצורפות בנספח( חיישנים אלו מחוברים אל "מכשיר" פיזי, מעין קופסה שחורה, הכוללת מיקרו בקר מסוג Arduino ורכיב Bluetooth המתקשר עם אפליקציה ייעודית בפלאפון/טאבלט האישי.

חיישן 2 חיישן 1 חיישן 3

הרעיון הוא שהמטופל מתנסה בכל סוגי החיישנים ובהדרכת הקלינאית מנסה להזיזם/להפעילם בצורות שונות. הקלינאית מקבלת חיווי במסך האפליקציה על תגובת החיישן לתנועות המטופל ועד כמה הוא מצליח למקסם את יכולות החיישן.

האפליקציה תיתן המלצה עבור החיישנים הרלוונטיי ם ביותר, כך שחיישן עבורו הצליח המטופל להגיע לטווח גדול יותר , שבפועל מגדיר יותר פעולות מוצא )נמדד במהלך הניתוח( הוא למעשה יותר רלוונטי - כמובן שהקלינאית תוסיף להמלצת האפליקציה שיקולים כמו נוחות וכו' בכדי להתאים בסופו של דבר את החיישן הטוב ביותר.

תרשים 1 - מבנה כללי של מערכת ניתוח היכולות

לפניכם מוצגת דיאגרמת בלוקים )תרשים 2( המסבירה את תזרים הנתונים העובר מרגע תחילת תהליך המדידה ועד להמלצות המוצגות לקלינאית התקשורת.


תרשים 2 - דיארגמת בלוקים עבור " מערכת ניתוח יכולות"

.4.1.1 האפליקציה
מטרת האפליקציה :

האפליקציה נועדה לקבל קלט/מידע מהחיישן של המטופל ובהתאם לערך המתקבל להציג חיווי במסך, בצורה ברורה )בהמשך ניתן לראות בתרשימי האפליקציה/בסרטונים את תצורת ההצגה המדויקת(. עבור כל חיישן יהיה מבחן שונה והתצוגה תהיה שונה. )עוד על כך בהמשך(. המטרה של תהליך ניתוח היכולות הוא לעזור לקלינאית התקשורת להבין איזה חיישן הכי מתא ים עבור כל מטופל.

סביבת פיתוח ושפה:

האפליקציה נכתבה בשפת Java עבור משתמשי אנדרואיד ובסביבת הפיתוח .Android Studio

סקירה של מסכי האפליקציה השונים )הנקראים Activities בשפת הפיתוח(:

חשוב לציין:
סקירה זו היא אינ ה מדריך למשתמש. אין הכוונה שמסקירה זו תדעו להפעיל את האפליקציה באופן מלא. הרעיון הוא לתאר את מסכי האפליקציה השונים ואת הרעיונות התכנותיים העומדים מאחוריהם. ע"מ להבין יותר את אופן פעולת המערכת אפשר לצפות בסרטונים בקישור הבא :

סרטוני הדרכה לאפליקציה (https://www.youtube.com/playlist?list=PLXXLm4EyRK1NrguGM9qZ6Np-806uYKIgE)

בנוסף מדריך למשתמש, מורחב ומפורט, יועבר לגורמים הרלוונטיים במקביל להדרכה מעשית.

מסך הבית של האפליקציה )תרשים 3(: (Main Activity)


במסך הבית א נ חנו יכולים להגיע אל כל חלקי המערכת. דבר ראשון שנעשה הוא חיבור אל רכיב הBluetooth בלחיצה על כפתור "BT TO CONNECT "תופיע רשימה של מכשירי Bluetooth זמינים.

אחרי שיתבצע החיבור נוכל גם להגיע מכאן אל תפריט בחירת החיישנים.

לצורך מימוש התקשורת עם הבקר בצורה חכמה, יצרנו קובץ פית וח בשם Bluetooth .Connector

כדי לשמור על חיבור ה- Bluetooth במשך כל ריצת האפליקציה ישנו Process ראשי )במונחי אפליקציה נקרא – Class Application )שפועל בכל זמן שהאפליקציה עובדת. הסיבה לכך היא, שבמידה והחיבור ייווצר ב thread/Activity ספציפי שעלול להיסגר במהלך הריצה, נאבד את המידע הרלוונטי לחיבור(.

תרשים 3 -מסך הבית של האפליקציה

מסך בחירת רכיב הBluetooth
:(ConnectToBluetooth Activity)


במסך זה אנחנו נרצה להתחבר אל התקן הבלוטות השייך למערכת הפיזית שיש לנו. במסך זה יופיעו כל התקני הBluetooth שמתואמים ) Paired )עם המכשיר שלנו. מסיבה זו, בשימוש ראשון של האפליקציה נצטרך "לחפש" את התקן הBluetooth דרך הגדרות הBluetooth של ה פלאפון ולשמור אותו.

לאחר שבחרנו את ההתקן המתאים, נראה הודעת התחברות ולאחר מכן הודעה בתחתית המסך האומרת לנו האם החיבור הצליח או לא .

תרשים 4 - מסך בחירת התקן ה- Bluetooth

מסך בחירת חיישן:
(SensorMenu Activity)


במסך זה הקלינאית תבחר באיזה חיישן המטופל יתנסה, כמובן שבהמשך ניתן לחזור למסך זה ולהתנסות בשאר החיישנים.

כחלק מהתקשורת בין מיקרו הבקר לאפליקציה, האפליקציה "מדווחת" לארדואינו באיזה חיישן אנו משתמשים כעת, על סמך בחירת החיישן, מיקרו הבקר שולח את המידע הרלוונטי עבור אותו חיישן בחזרה לאפליקציה.

תרשים 5 - מסך בחירת החיישן

מסכי החיישנים:

במסכים אלו נתחיל את התנסות המטופל, המדידות וניתוח היכולות.

לכל סוג חיישן )אנלוגי/ בינארי/ ג'ויסטיק( יש מסך מדידה שונה – נראה בהרחבה בהמשך.

על המסך תופיע "משימה" )הגעה למטרה/מילוי "מבחנה" בגובה משתנה וכו'( אותה יידרש המטופל לבצע ע"י תנועה/ פעולה עם החיישן.

המשימות יבחנו יכולת רגישות/תגובה עם החיישן ותזמון בין פעולות שונות/ זהות ועוקבות עם החיישן במקצב מסוים .

בחלק מהחיישנים תהיינה דרגות קושי שונות עבור פעולות זהות למשל שינוי גדול המטרות אליהן צריך להגיע.

במקביל להצגת המבחנים על המסך קיים ברקע האפליקציה, ישנו אובייקט שנקרא .DiagnosisDataCollector

אובייקט זה מהווה מבנה נתונים מסוג HashMap שנועד לשמור את "הצלחות" המטופל עם החיישנים השונים. בסיום ההתנסות וניתוח היכולות, נסכם את יכולות המטופל על סמך בסיס נתונים זה ונקבל המלצה באילו חיישנים כדאי לעבוד, כמו גם, כמה פעולות שונות יכול לבצע המטופל בעזרתם. בהמשך, מספר הפעולות השונות יתורגם במערכת העזר לפעולות שיבחר המטופל כמו הפעלת מזגן/קריאה לעזרה וכו' .

- מסך חיישן הג'ויסטיק (Activity JoystickSensor (:

תרשים 6 - מסך חיישן הג'ויסטיק

מסך זה מתאים לחיישן מסוג ג'ויסטיק בלבד

במסך זה המטופל נדרש להגיע עם הכדור הצהוב אל המטרות השונות.

ישנם 3 שלבים שונים כשבכל שלב גודל המטרה שונה.

כא שר "נפגע" במטרה נקבל איתות קולי להצלחה והמידע ישמר בבסיס הנתונים כפי שפורט לעיל.

ניתן בכל זמן לעשות RESET ולאפס את המדידה.

מסך החיישן הבינארי(Activity OnOffSensor(:

תרשים 7 - מסך החיישן הבינארי

מסך זה יתאים לכל חיישן בינארי שהוא )בין אם זה כפתור או חיישן כספית שסוגר מעגל ע"י הזזה וכן הלאה(.

המטרה היא בעזרת החיישן הבינארי להפוך את הנקודה האדומה לירוקה )ע"י לחיצה על כפתור למשל(.

בשלב השני המטופל נדרש לבצע את אותה תנועה פעמיים במרווח שלא יעלה על 2 שניות, הרעיון הוא למצוא דרך לאפיין 2 פעולות שונות בעזרת אותה התנועה עם החיישן.

במידה והמטופל מצליח בחלק השני – קיבלנו אפשרות של שני מצבים שונים. מצב אחד הוא לחיצה בודדת ומצב שני הוא לחיצה כפולה )בתוך 2 שניות, בדומה לעכבר מחשב(. במידה והמטופל לא מצליח, כלומר שתי התנועות שביצע הן במרווח העולה על 2 שניות, מדובר בעצם בפעולה אחת שקרתה פעמיים.

מסך החיישן האנאלוגי(Activity AnalogSensor(:


תרשים 8 מסך החיישן האנאלוגי

מסך זה, יתאים לכל חיישן אנאלוגי שהוא )חיישן כיפוף, חיישן מרחק וכו'(.

האפליקציה מקבלת ערכי מתח שונים )בין 0 ל5 וולט, המיוצגים בין הערכים 0 ל1024-( מן הארדואינו בהתאם למצב החיישן. )לדוג' בחיישן כיפוף, רמת הכיפוף הגבוהה ביותר תיתן לאפליקציה ערך של 1024( האפליקציה מצידה מציגה בהתאמה את רמת המילוי ב"מבחנה" כפי שניתן לראות בתרשים .8

מטרת המטופל, היא לשל וט על היכולת "למלא" את המבחנה עד לאזור מסוים )התחומים בין השנתות(.

אינדיקציה זו נותנת לנו מידע על יכולת המטופל לשלוט בחיישן.

ניתן להוריד/לעלות רמה, כך שטווח המבחנה יתחלק למספר גדול/קטן יותר של תחומים – כמובן שכמו בשאר מסכי האפליקציה, המידע על הצלחה במדידה נאסף במבנה נתונים משותף לכלל האפליקציה, כפי שתואר לעיל.

.4.1.2 מיקרו בקר - ארדואינו

ַארְ דּואִ ינו (https://www.arduino.cc/) הוא מיקרו-בקר בעל מעגל מודפס יחיד, עם סביבת פיתוח משולבת ברישיון קוד פתוח, אשר מטרתה ליצור סביבה נוחה וזולה לפיתוח פרויקטים המשלבים תוכנה עם רכיבי אלקטרוניקה. לארדואינו קהילת משתמשים גדולה ומדריכים מקוונים המסייעים להוריד את חסם הכניסה לתחום הפיתוח המשלב חומרה ותוכנה. )ויקיפדיה(

בפרויקט שלנו בחרנו להשתמש בלוח Uno Arduino( תרשים 9( בעבור שתי המערכות, מערכת ניתוח היכולות ומערכת העזר. בקר זה הינו נוח לתכנות וניתן לכתוב לו קודים פשוטים בשפה המתאימה במיוחד לארדואינו ומתבססת על שפת C/CPP. לוח הארדואינו כולל 6 פורטים אנלוגיים 5A0-A( יכולים להכניס/להוציא מתחים בטווח של V-5V0 )ו14 פורטים דיגיטליים )ערכים בדידים של מתח V5 או V0).

תרשים 9 - לוח ארדואינו מסוג Uno

להלן דוגמה המפרטת )תרשים 10( את אופן החיבורים והתקשורת בין החלקים השונים במערכת ניתוח היכולות בדוגמא זו החיישן המחובר הוא ג'ויסטיק:


*Rx/Tx הינם פורטים ייעודיים לUART( יפורט בהמשך( עבור קליטה ושידור )-T ,receiver-R ) transmitter
הסבר על אביזרי הקלט השונים )"חיישנים"(

בפרויקט שלנו השתמשנו בשני סוגים עיקריים של אביזרי קלט )"חיישנים"(, אנלוגיים ודיגיטליים.

החיישנים האנלוגיים נותנים לנו טווח של ערכים )0-1024 עבור מתח V5 ) בעוד שהחיישנים הדיגיטליים נותנים לנו שני ערכים בלבד גבוה ונמוך ואותם נפרש כ0 ו1

פירוט החיישנים שיש לנו:

- דיגיטליים:
1( חיישן לחיצה )כרית לבנה – תמונה בנספח( 2( חיישן לחיצה – מורס. דומה ברעיונו ללחצן רגיל אך הוא לחצן שקל ללחוץ עליו והוא כולל תושבת חזקה ויציבה שניתן להניחה מתחת לידו של המטופל.)תמונה בנספח(
- אנלוגיים:
1( ג'ויסטיק – חיישן אנלוגי בעל שני ערכים X,Y שכל אחד מהם נותן מספרים בטווח שבין 0 ל1024
2( חיישן גבה - מבוסס על חיישן המסוגל למדוד עוצמה של שדה מגנטי המוטמע בתוך אביזר)מבוסס על אפקט Hall). האביזר מורכב מפלסטיק בעל שני חלקים כאשר חלק אחד)המגנט( יושב על הגבה וחלק שני)החיישן( יושב על המצח. שני החלקים

תרשים -10 מערכת ניתוח היכולות -בחיבור לאביזר הג'ויסטיק

מוצמדים לרצועות גומי המתחברות מסביב לראשו של המטופל. הזזה של הגבה גורמת למגנט להתקרב לחיישן. 3( חיישן מרחק - נותן לנו טווח מספרים שמייצג את המרחק של האובייקט הנמדד מהחיישן.

תרשים 12 - מודול מסוג ג'ויסטיק

תרשים 13 - חיישן למדידת שדה מגנטי תרשים 14 - כפתור לחיצה

תרשים 16 - חיישן כיפוף - Gauge Strain

תרשים 15 - חיישן מרחק מסוג Ultrasonic

תרשים 11 - חייש מרחק מסוג לייזר

תקשורת בלוטות' סריאלית

צורת התקשורת שלנו עם מודול הבלוטות היא בצורה סריאלית בעזרת פרוטוקול
UART -Universal Asynchronous Receiver Transmitter | התקשורת
)בעברית "מקלט משדר אסינכרוני אוניברסלי" (

במקור יחידת ה- UART הייתה חיצונית למיקרו בקר אבל היום היא פנימית בתוכו )זה למשל מה שקורה בארדואינו שלנו(

מידע מהרשת בנושא (https://www.circuitbasics.com/basics-uart-communication/) UART (https://www.circuitbasics.com/basics-uart-communication/)

בפרוטוקול זה המידע מועבר ב"מסגרות", מעין בלוקים של מידע.

מבנה המסגרת הוא :

כל זמן שאין שידור מתח המוצא נשאר ברמה גבוהה )מתפרש כ1 לוגי(, בתחילת שידור המידע, נשלחת סיבית אח ת בעלת מתח נמוך )0 לוגי(, לאחריה יתר הסיביות של המידע, ולאחריהן סיבית הזוגיות האופציונלית ולבסוף סיבית סיום גבוה ה )1 לוגי(.

ל UART יש מספר די מצומצם של קצבי שידור, והם ,50 ,300 ,1200 ,2400 ,4800 ,9600 ,14400 ,19200 ,28800 57600 ו115200- סיביות (https://he.wikipedia.org/wiki/%D7%A1%D7%99%D7%91%D7%99%D7%AA) לשנייה. (https://he.wikipedia.org/wiki/%D7%A9%D7%A0%D7%99%D7%99%D7%94)

צורת התקשורת למודול ה Bluetooth זהה לתקשורת עם UART רגיל.

קצב העברת הנתונים אצלינו הוא 9600 BAUDRATE.

### .4.2 מחולל קוד להתאמת מערכת העזר האישית

כדי לגשר בין מערכת הניתוח הנ"ל הנותנת לנו מידע על החיישן המומלץ לשימוש, ובין מערכת העזר האמורה להתאים ליכולותיו ולצרכיו האינדיבידואליים של המטופל. יצרנו באפליקציה מחולל קוד אישי.

רעיון המחולל הוא כזה:
המשתמש במחולל בוחר איזה חיישן הוא הולך לחבר למערכת העזר שהוא יוצר כרגע. בנוסף, המשתמש בוחר את כלל פעולות המוצא)מוגדר בצורה מפורטת להלן(. לפי בחירות אלו המחולל שבאפליקציה ייצור קוד מותאם אישית.

יתרון המחולל הוא שניתן ליצור מערכת עזר מותאמת אישית בצורה פשוטה ונוחה. תהליך יצירת הקוד נעשה ע"י מילוי של שאלון במסך האפליקציה המתאים, כך שגם מי שאינו מבין באלקטרוניקה או במחשבים יוכל ליצור מערכת שכזו עבור מטופל.

תהליך פשוט זה מתואר בדיאגרמה הבאה )תרשים 17( המציגה מספר את תרשים זרימה של פעולת מחולל הקוד.


תרשים 17 - דיאגרמת בלוקים מחולל קוד אישי


תרשים 18 - מסך המחולל )חלק 1(

נגדיר שתי הגדרות:

מצבי חיישן - המצבים השונים אליהם חיישן יכול להגיע באופן כללי. בג'ויסטיק למשל מדובר במרחק מסוים ב4 כיוונים )קדימה, אחורה, ימינה ושמאלה(. בחיישן מסוג לחצן, זה יכול להיות מצב אחד בלבד- לחיצה. או במקרה מורכב יותר לחיצה וגם לחיצה כפולה.

פעולות מוצא – כלל השימושים היכולים להיעשות ע"י המכשיר נקראים פעולות מוצא . הפעלת מזגן/ הפעלת אור/ שיחה/ קריאה לעזרה וכו'

אופן השימוש במסך האפליקציה )תרשימים 18-19(:

- בחירת חיישן - ראשית בוחרים את סוג החיישן המתאים )בהתאם להמלצות השלב הקודם ובשקלול דעתה של קלינאית התקשורת(
- בחירת אופן שימוש - בוחרים את אופן השימוש בחיישן זה )רלוונטי בעיקר לחיישנים בינאריים( בהתאם ליכולות המטופל.
- בחירת הפעולות הנדרשות - לאחר מכן בוחרים בשאלון את פעולות המוצא המתאימות לכל אחת ממצבי החיישן האפשריים. )סוג מצבי החיישן ומספר ם נקבע על פי סוג החיישן ויכולות המטופל(

לדוגמה - עבור חיישן מסוג כפתור, במצב בו המשתמש יכול ללחוץ לחיצות כפולות יפתחו אפשרויות בחירה עבור 2 פעולות.

פעולה אחת עבור לחיצה ופעולה שנייה עבור לחיצה כפולה )בדומה לשימוש בכפתור העכבר במחשב שבמבצע פעולות שונות עבור סוגים שונים של לחיצות(


תרשים 19 - מסך המחולל )חלק 2(

כלל פעולות המוצא שיכולות להתבצע ע"י מערכת העזר הן:

1( הדלקה/כיבוי מזגן ) או כל אביזר אחר בעל שלט(
2( הדלקה/כיבוי אור ) או כל מכשיר חשמלי בעל צריכת חשמל לא גבוהה( 3( הפעלת צפצוף לעזרה
4( צלצול לטלפון
5( שליחת SMS מוגדר מראש
6( וכו'

על המשתמש לבחור עבור המטופל את פעולות המוצא הנדרשות לו, מתוך רשימה זו.

- בעת סיום מילוי השאלון המשתמש לוחץ על כפתור " System unique create "המופיע בתרשים .18
ברגע זה המערכת יוצרת קובץ קוד המותאם לבחירותיו של המשתמש. )קוד לדוגמא מופיע בנספח(
- המערכת מעבירה את המשתמש אוטומטית אל מסך שיתוף שבו הוא צריך לשלוח את הקובץ. המשתמש ישלח את הקובץ למחשב שממנו תתבצע "צריבת" התוכנה. צריבת הקוד אל הארדואינו נדרשת כדי שלוח הפיתוח מסוג הארדואינו יכיל את הקוד האישי שיצרנו.
את הקובץ ניתן לשתף בכל אפליקציית תקשורת שהיא )מייל, WhatsApp וכו'(.
- בשלב זה, כדי להשלים את תהליך יצירת מערכת העזר על המשתמש לקחת מערכת עזר ריקה/מחודשת ולחבר אותה למחשב ובנוסף לחבר את האביזרים הדרושים: .1 החיישן שנבחר בעת יצירת הקוד .2 אם יש צורך, אביזרים היקפיים המתאימים לפעולות הנבחרות: ) למשל מתאם החשמל – Relay ,עבור מנורת קריאה(.

תרשים 20 - מסך שיתוף קובץ הקוד

- על גבי המחשב, על המשתמש למקם את הקובץ האישי בתוך התיקיה c:\MIlbatApp
בה יש את קובץ ההרצה RUN_ARDUINO( תרשים 21(וכן את כל הקבצים ההיקפים המכילים את כל שאר הקוד הדרוש ליצירת מערכת העזר. כעת יש ללחוץ על הקובץ ....ו ARDUINO_RUN

זהו!
מערכת העזר מוכנה! כרגע נותר רק לבדוק שהיא עובדת.

תרשים 21 - לחיצה אחת והקוד מוכן על המכשיר!

### .4.3 מערכת העזר

בחלק זה נתאר את מבנה המערכת והלוגיקה העומדים מאחוריה.

עד כה הצגנו את מערכת העזר כקופסה שחורה סגורה בעלת יכולות לבצע מגוון של פעולות על פי צרכיו של ה משתמש. פרק זה יהיה מעין מבט פנימה ובו נפרט על החלקים השונים ותפקידיהם.

### מבנה המערכת:

מערכת העזר לעיל )תרשים 22( מחולקת לשלושה חלקים. החלק שמופיע בתוך הריבוע השחור הוא החלק הנמצא בתוך המארז. החלק הימני המופיע במלבן הירוק הוא מתאם התאורה. החלק האדום הוא החיישן הנבחר, ובמקרה הזה, הג'ויסטיק.

המארז מכיל את החלקים הבאים:

- מסך LCD לצורך חיווי. המסך מציג את הפעולות הנעשות כעת במערכת או את המידע הדרוש לצורך תכנות פעולות ספציפיות אל תוך ההתקן.
- שני כפתורי תכנות )בתרשים – הכפתורים הם בצבע אדום( נועדו להכניס אותנו אל מצב תכנות. מצב תכנות נועד בשביל שת היה למשתמש את היכולת להכניס מידע אל ההתקן אף לאחר צריבתו בהליך הראשוני ע"י המחשב. לדוגמא - הקלטת קודים של פעולות השלט של המזגן ) ועל כך נרחיב בהמשך(.
- זמזם - בתוך הערכה מותקן זמזם אשר פועל לחיווי הפעלת מצבי החיישן. בצורה זו יכול המטופל לשמוע חיווי קולי לכך שהוא מפעיל את החיישן במצבים השונים)במילים אחרות – חיווי לכך שהקלט אכן התקבל במערכת(.

בנוסף הזמזם יכול להשמיע צפצוף של קריאה לעזרה כאשר המטופל מפעיל את הפעולה הנ"ל.
- מודול Bluetooth – נועד לתקשורת עם מכשיר הפלאפון )שיחת חירום/שליחת הודעה(
- חיבורי USB – חיבורים אלו נועדו להוות חיבור קל ופשוט של אביזרים היקפיים כגון חיישנים והתקנים נוספים. אין מדובר בשקע USB רגיל המתפקד בדומה לשקע USB הקיים במחשב. מדובר בשימוש בחיבור הפיזי בלבד על מנת ליצור חיבור נוח אמין וקל.
- רכיבי שליטה במזגן )או כל מכשיר אחר בעל שלט IR )- לד IR, טרנזיסטור 2222N2 Receiver_IR
רכיבים אלו מאפשרים תפעול של מזגן.)ועל כך נרחיב בהמשך(.

בנוסף למארז של מערכת העזר יש לנו את מתאם התאורה )שיכול להתאים גם לכל מכשיר חשמלי, בעל צריכת חשמל נמוכה(.

המתאם בנוי מבית נורה וממסר )Relay )שיושב בתוך קופסה לבנה.

אופן פעולת מתאם התאורה:

הממסר מקבל אות חשמלי חלש )5 וולט( מן לוח הארדואינו אשר במארז, בתגובה הוא יודע למתג את המתח הנכנס אליו )220 וולט AC). הממסר עובד בעזרת עיקרון פשוט של חשמל ומגנטיות.


בממסר יש סליל ומתג מתכתי )תרשים 24 (. כאשר הממסר מקבל מתח )5 וולט( מן הארדואינו יש זרם הזורם בסליל. זרם זה בתוך הסליל יוצר שדה מגנטי. השדה המגנטי גורם להזזה של המתג המכני המתכתי ובכך נסגר המעגל של זרם החילופין 220 וולט והמנורה נדלקת.

תרשים 23 - אופן פעולת הממסר

הסבר מורחב על השליטה במזגן
על מנת לשלוט במזגן אנחנו פועלים בשני שלבים. בשלב ראשון עלינו "להקליט" את הפעולה אותה מבצע השלט של המזגן אותו אנו רוצים להפעיל. בשלב השני אנחנו משדרים את האות המוקלט דרך לד הIR ובכך מפעילים את המזגן.

אינפרה אדום:

אינפרה אדום הוא אור שלא בספקטרום האור )תרשים 25( הנראה בעין אנושית.


כיום ישנם פרוטוקולים רבים לשימוש בIR, אך הנפוצים ביותר משתמשים בשיטה הבאה: אות הIR נדלק בתדירות של Khz ,38 אך הפרשים שונים בין ההדלקות מתפרשות ל – 0 ול – 1 כך:


תרשים 26 - קידוד אינפרא אדום בשלט סטנדרטי

תרשים 25 - אינפרה אדום על ספקטרום האור

איך עובדת פקודת IR בשלט מזגן:

מרבית שלטי המזגן עובדים כמשדרי מצב ולא כמשדרי פקודה בודדת. )כלל האצבע כדי לדעת – כל השלטים שבהם יש מסך בשלט עצמו הם משדרי מצב( לחיצה על כפתור בשלט המזגן אינה משדרת למזגן פקודה בודדת אלא היא משדרת לו את המצב בו הוא צריך להיות, ללא תלות במצבו הנוכחי של המזגן.

לדוגמא כאשר יהיו מולנו 2 מזגנים זהים:

האחד פועל במצב טורבו, קירור, 18 מעלות השני יהיה במצב עבודה רגיל, חימום, 30 מעלות.

כאשר נעלה מעלה צלזיוס אחת בשלט המתאים לשניהם )אשר בו המצב כרגע הוא קירור בטמפרטורה של 23 מעלות(, התוצאה תהיה היא ששני המזגנים יעברו לאותו הסטטוס כפי שמתואר בשלט – קירור על 24 מעלות.

זאת בשונה מהמקרה של שתי מערכות סטריאו. במקרה זה יש לנו שתי מערכות זהות אחת ליד השנייה במצב התחלתי של ווליום שונה בכל אחת מהן. כאשר נגביר את הווליום בשלט, כל אחת ממערכות הסטריאו תגדיל את ערך הווליום שלה באחד ולא יקרה מצב ששתיהן יעברו לאותו ערך ווליום.

במילים אחרות - כל אות אינפרה אדום של שלט מזגן מכיל בתוכו את כל ההגדרות/הנתונים הרלוונטיים עבור סטטוס ההפעלה הרצוי.

מסיבה זו, כל פעולת מוצא הקשורה במזגן, כמו הדלקה, מבטאת בתוכה סטטוס שלם. לכן, אם "נקליט" פקודה של - הדלקה על קירור בטמפרטורה של 20 מעלות. פקודה זו תמיד תדליק את במזגן במצב המוקלט ונצטרך פעולה נוספת על מנת להדליק את המזגן במצב אחר.

איך קלטנו ואיך שידרנו: )לד אינפרה אדום, רכיב Receiver IR)

את קבלת אות האינפרה-אדום הרצוי קלטנו בעזרת מקלט מסוג Receiver IR המתחבר לארדואינו כפי שניתן לראות ב תרשים .27


את המידע המתקבל מהמקלט ניתן לפענח לפי פרוטוקולים שונים. מכיוון שלא רצינו להגביל את עצמינו רק עבור מזגנים המשתמשים בפרוטוקול ידוע כזה או אחר, בחרנו להשתמש בספרית הארדואינו IRremote.

)הספרייה נתמכת רשמית בסביבת הפיתוח של ארדואינו(

ספרייה זו מקבלת את המידע בצורה גולמית ומאפשרת בהמשך שליחה שלו בצורה זהה.

שידור האות נעשה ע"י חיבור נורת לד אינפרה אדום כפי שמתואר בתרשים. בקוד הארדואינו השתמשנו בספריה שהוזכרה לעיל.

תרשים 27 - חיבור IR Receiver

הוספת טרנזיסטור
בהתחלה שידרנו את אות האינפרה להדלקת המזגן ו הבחנו שהאות די חלש )אפילו כשההדלקה מתבצעת רק במרחק 0.5-1.5 מטרים מהמזגן(. לאחר התייעצות עם ד"ר אברהם שלי וחיפוש נרחב באינטרנט התברר לנו שלוח הארדואינו אינו מספק זרם חזק דיו, הדרוש ללד האינפרה אדום, ביציאות הרגילות שלו אלא רק בחיבור ישיר למתח 5 וולט ומעלה.


מסיבה זו חיברנו את הלד בעזרת טרנזיסטור )תרשים 28( ליציאת 5 וולט של הארדואינו. הטרנזיסטור למעשה משמש כמתג להדלקת הלד )ממקור המתח 5 וולט( ו Port היציאה שולט עליו ע"י הזרמת מתח אל ה Gate של הטרנזיסטור. )המתח המגיע מפורט זה גורם לטרנזיסטור לאפשר את הזרם המחובר ל ל5 וולט( כפי שניתן לראות בשרטוט.

פתרון זה נתן לנו אפשרות שליטה על המזגן.

כיוון שכל טכניקת שליטה על מזגנים מבוססת אינפרה אדום למעשה "הונחו היסודות" לשליטה על כל מכשיר מבוסס אינפרה אדום כמו טלוויזיה ואף לכל מערכת בית חכם הכוללת בתוכה שימוש רב באותות אלו .

שמירת הערכים המוקלטים בזיכרון הפנימי של המיקרו-בקר

פקודת IR של מזגן נשמרת בצורה גולמית כמערך מספרים )int )של בין 50 ל400 מספרים. מספרים אלו מבטאים את הפרשי הזמן שבין הדלקות הIR לד.

רצינו לשמור את הערכים הללו בArduino כך שגם לאחר ניתוק המכשיר מהחשמל ישמרו הערכים הללו. כדי לשמור את הערכים הללו השתמשנו בזיכרון הEEPROM של הארדואינו. זיכרון זה אינו נמחק גם לאחר ניתוק הבקר מהחשמל.

בצורה זו אנו יכולים לשמור על הערכים מהפעלה להפעלה מבלי להצטרך זיכרון חיצוני כגון כרטיס זיכרון.

תרשים 28 - חיבורי הIR עם הטרנזיסטור

## .5 מסקנות וסיכום

### .5.1 האם התוצאות מתאימות לניתוח הראשוני?

בניתוח הראשוני הועלו רעיונות נוספים שלא מימשנו כמו שימוש באפליקציות צד שלישי בעזרת החיישנים. בנוסף ההגדרות למערכת ניתוח היכולות היו "גמישות" יותר, למשל באיזו דרך ניתן לקודד פעולות שונות ע"י תנועה אחת )חזרה על התנועה/ משך זמן התנועה וכן הלאה(.

כמו כן הועלה רעיון ליצירת קובץ סיכום הניתוח עבור שימוש עתידי.

בסופו של דבר הפתרון התכנס למערכת שיצרנו כשהשיקולים שהיו לנגד עינינו –לקבל את מערכות הניתוח והעזר הטובות ביותר בהתאם ללוח הזמנים הנתון.

מאחר והפוטנציאל במערכת זו הוא גדול - השמיים הם הגבול, ואכן ניתן להגיד שהתוצאה בהחלט תואמת לציפיות שלנו בתחילת התהליך ואף עולה עליהן.

בסופו של דבר עמדנו בדרישות הפרויקט במלואן ובצורה מוצלחת. כפי שניתן לראות בסרטוני ההדגמה של מערכת העזר לינק (https://www.youtube.com/playlist?list=PLXXLm4EyRK1NrguGM9qZ6Np-806uYKIgE)
קיבלנו תוצאות משביעות רצון עבור תהליך המדידה וכן עבור תפעול של הדלקת המזגן, שיחת טלפון, שליחת SMS והדלקת מנורה.

דאגנו לפתח מערכת שנותנת מענה הן מבחינת הקלט הנכנס והן מבחינת פעולת המוצא . מערכת זו נותנת מענה לכל אדם עם מוגבלות וזאת עם אפשרות התאמה אישית. כל זה בעזרת תהליך קל ונוח וזמין.

כלל התהליך הוא ללא מגע של מתכנת או מפתח. יצרנו מערכת סגורה הנותנת אפשרות ליצירת מערכת עזר מותאמת אישית גם למי שאינו מבין בתחום. כמובן שיש תמיד מקום להוסיף ולשפר וברצוננו להמשיך ולפתח את המערכת בעתיד אך אנו ומנחינו סבורים שהפתרון המוצע כרגע הוא הישג יפה. כמובן שמבחינתנו שימוש המטופלים במערכת וקבלת חוות דעת/פידבקים מהאנשים הזקוקים למערכת זו, הם אלו שיתנו לנו את החותמת האמיתית להצלחת המערכת.

נציין שלצערנו לאור המצב ומגבלות הקורונה לא הייתה לנו אפשרות להפעיל את המערכות בשטח עם המטופלים.

יתרונות וחסרונות של הפתרון

יתרונות

המערכת היא זולה, מדובר בעלות חומרים של כ50-80- שקלים לכל יחידה )בגרסה המתבססת על מוצרים סיניים(

דבר זה מאפשר לנו לתת מערכות עזר לאלו הזקוקים להן גם אם אין ידם משגת אבזור יקר העולה הרבה כסף.

המערכת ניתנת לשדרוג בקלות יחסית, ניתן להוסיף לה עוד חיישנים במאמץ מינורי, כמו גם ביצוע פעולות חדשות בעזרת החיישנים.

חסרונות – כל הרכבה של מערכת חדשה מצריכה ידע מדויק על אופן החיבורים, ולכן לא יכולה להיעשות ע"י כל אחד שירצה אלא מי שבין בתחום.

### .5.2 הקשיים שפתרנו

- אחד הקשיים המשמעותיים שהיו לנו לכל אורך הדרך הייתה העובדה שאת מרבית החומר התאורטי נאלצנו ללמוד לבד. את כל נושא האנדרואיד למשל, היינו צריכים ללמוד מאפס. בנוסף נושא ה Bluetooth הוא לא פשוט כלל, והוא הצריך מאיתנו שבועות רבים של תכנות.
- העבודה היא מרמת החוט עד רמת המוצר השלם: בפרויקט זה שימשנו בהרבה כובעים. היינו מתכנתים של אפליקציה, מתכנתים של מערכת מוטמעת קוד שרץ בזמן אמת )ארדואינו(. מהנדסי אלקטרוניקה מעצבי מוצר של מארזים ואף הלחמות של חוטים. העבודה בכובעים רבים היא אמנם מעניינת ומאתגרת אך מטבע הדברים מאטה את קצב ההתקדמות של הפרוייקט כאשר צריך לעשות כל כך הרבה דברים במקביל.
- הקושי בהפעלת המזגן – קוד הפעלת המזגן מכיל מורכבויות רבות כפי שתואר בפרק 5.3 יש צורך לשלוח כמויות גדולות של מידע ולכל מזגן אורך שונה של קוד וכן פרוטוקול מעט שונה להפעלה. בנוסף צריך לאחסן את כל הנתונים על גבי המיקרו בקר- גם זו משימה לא קלה.

### .5.3 אפשרויות לפיתוח עתידי

- חווית שימוש ופידבקים - קבלת פידבק ממטופלים להתאמה טובה יותר של המוצר.
- קישוריות מורחבת - יצירת מערכת עזר שמתפקדת בבית חכם )התממשקות יותר טובה עם כלל האביזרים החכמים(
- שדרוג הבקר - מעבר לעבודה עם 32 ESP במקום Uno Arduino
- הרכיב קטן יותר ותופס פחות מקום.
- יש לו תמיכה בWIFI מה שפותח את הפתח לעולם רחב יותר של הפעלות מוצרים. הקישור לבית חכם נהיה הרבה יותר פשוט וקל.
- יש לו תמיכה ב BLE( Energy Low Bluetooth). אמנם זה יותר מסובך לתפעול בטווח הקצר אך זה יעיל וחוסך אנרגיה/סוללה בטווח הארוך.
- עלות נמוכה
- שדרוג המארז - יצירת דגם תלת ממדי שבתוכו ימצאו המערכות. שדרוג כזה יקנה נוחות ואמינות. המערכת תהיה הרבה יותר נוחה לשימוש וכמובן שיותר עמידה. בנוסף החיווט יהיה בחיבורים חזקים ובהלחמות מקצועיות.
- שדרוג האפליקציה - שדרוג שיאפשר לשמור את כל הנתונים במסד נתונים כך שנוכל, במידת הצורך, לשלוף אותם בעתיד.
- הוספת י יעוד למערכת הניתוח - שימוש באפליקציה לא רק לצורכי ניתוח יכולות אלא גם לצורכי אימון )למשל משחק שבו צריך לאמץ את האצבע כדי להזיז – פותח פתח לעולם של שיקום פיזיולוגי(
- שדרוג חיבורים - שדרוג חיבור הUSB לחיבור נוח יותר ואמין יותר )במידה וקיים כזה(, חיבורי מערכת יותר ידידותיים וקומפקטיים )קשור גם לעיצוב המוצר(

## .6 תודות

ראשית ברצוננו להודות לד"ר ססיל יחזקאל וד"ר אברהם שלי על כך שליוו אותנו במהלך הפרויקט.

תודה גדולה לתומר לוקר על כך שפיתח את חיישן הגבה ואת התבנית התלת ממדית המאפשרת חיבור נוח של החיישן. שבו אנו משתמשים.

תודה לראם חלמיש, חבר מן העבר, שנענה לבקשת העזרה שלנו בפייסבוק. ראם עזר לנו עם לימוד האנדרואיד ברמה הבסיסית בכך שהפנה אותנו לקורס אינטרנטי מתאים. בנוסף ראם עזר לנו מאוד בכל נושא הקישוריות של הBluetooth. נושא שללא ספק היה אבן נגף בכל שלבי תכנות האפליקציה. ראם עזר לנו ליצור מערכת פשוטה ויציבה שעזרה לנו להתמודד עם קישוריות ה Bluetooth. זו הייתה עזרה גדולה ועל כך תודתנו.

תודה לחברי קבוצת הפייסבוק "ארדואינו" ובפרט למוטי בזר על כך שנתן לנו כמה עצות טובות ומועילות לגבי תפעול שלטי המזגן במערכת העזר. נושא שגם היה לא פשוט כלל.

## .7 רשימה ביבליוגרפית

- קורס אנדרואיד למתחילים של האתר Udemy https://www.udemy.com/course/the-complete-android-oreo-developer-course
- האתר הרשמי למתכנתים באנדרואיד https://developer.android.com/
- האתר הרשמי של Arduino
/https://www.arduino.cc
- מוטי בזר וכל שאר חברי קבוצת "ארדואינו ישראל" בפייסבוק /https://www.facebook.com/groups/arduinoisrael
- תוכנת Fritzing - שרטוטים של כלל המערכות /https://fritzing.org
- סרטון של אלכס שו בנושא המזגנים https://www.youtube.com/watch?v=67IEmopqE9A

## .8נספחים

### - מדריך וידאו ל משתמש במערכת

למדריך הוידאו המלא (https://www.youtube.com/playlist?list=PLXXLm4EyRK1NrguGM9qZ6Np-806uYKIgE)

### - כל הקוד של האפליקציה של הפרויקט מופיע באתר GitHub:

### https://github.com/brkrot/AlsHelper

### - קוד לדוגמא מערכת עזר

### https://1drv.ms/u/s!AvT1w8UFettt4nHoFZdsPF2Ux0Ys?e

### =8eLRMs (https://1drv.ms/u/s!AvT1w8UFettt4nHoFZdsPF2Ux0Ys?e=8eLRMs)

### - צילומים של המערכת מופיעים בעמודים הבאים

# תמונות אב טיפוס מערכת העזר

# מבט חיצוני


# תצוגת מסך

## לחיצה על מצב חיישן "ימינה" בחיישן ג'ויסטיק


# מבט פנימי

# חיישן כפתור לחיצה קלה


# חיישן כפתור חיצה קלה

# מבט על הכפתור שבפנים


# חיישן מורס


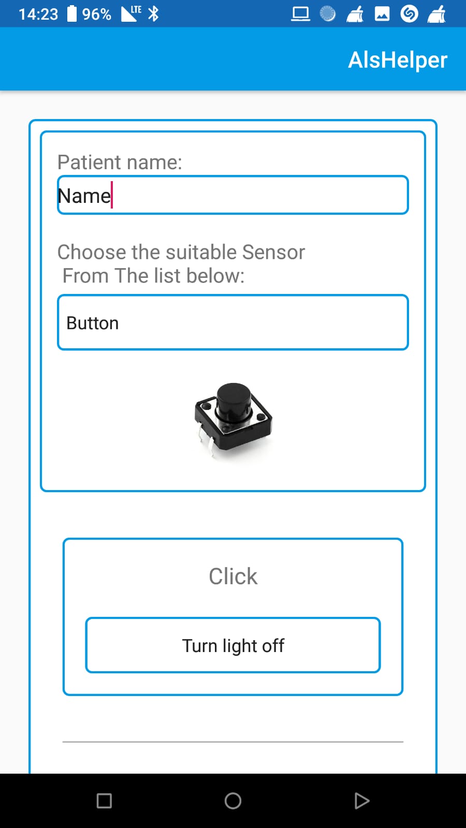
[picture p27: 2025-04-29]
Documents/צילומי מסך אפליקציה/מסך מחולל קוד 1.jpg

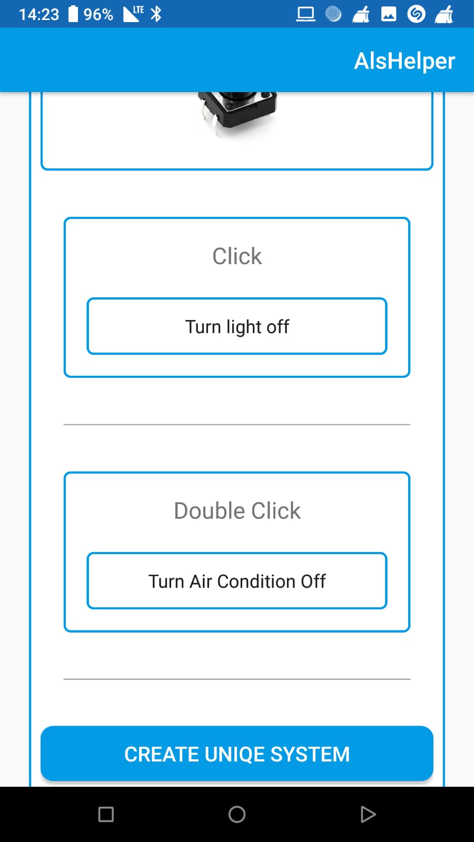
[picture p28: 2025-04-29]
Documents/צילומי מסך אפליקציה/מסך מחולל קוד 2.jpg

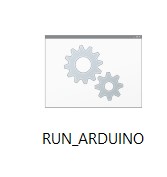
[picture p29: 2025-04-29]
Documents/תרשימים/Batch file.jpg

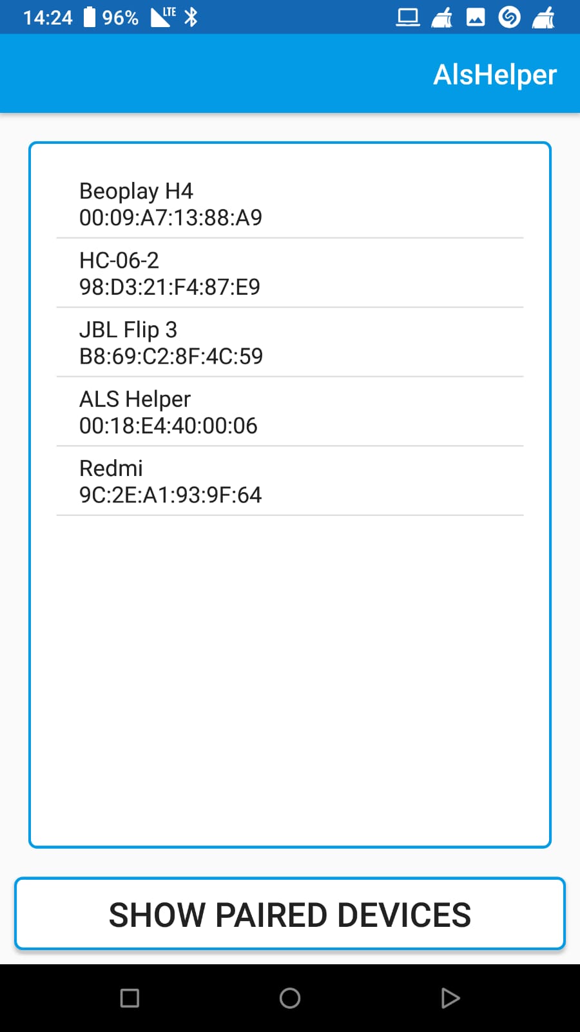
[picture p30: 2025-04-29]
Documents/צילומי מסך אפליקציה/מסך התקני בלוטות מתואמים.jpg

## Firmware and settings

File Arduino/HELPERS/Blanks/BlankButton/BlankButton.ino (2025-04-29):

/*This code is written especially for #PATIENT_NAME*/

/********************* Includes ***************************/
#include <IRremote.h>
#include <EEPROM.h>
#include <AceButton.h>
using namespace ace_button;
/*********************Constants*********************************/

#define DEBUG 1
#define FUNC_TAGS 1


#define LCD_DELAY_TIME 5000

/*********************Ports*********************************/

#define BUZZER 7
#define LEFT_PUSH_BUTTON 12
#define RIGHT_PUSH_BUTTON 9
#define RELAY_LIGHT 8

// The pin number attached to the button.
const int BUTTON_PIN = A1;


/****************Variables*********************************/

AceButton button(BUTTON_PIN);
unsigned long lastTime = 0;
unsigned long currentTime = 0;
int xData = 0;
int yData = 0;
char currentDirection = 'N';
boolean setupMode = false;
int leftButtonVal = 0;
int rightButtonVal = 0;

void handleEvent(AceButton*, uint8_t, uint8_t);

/**
  The function beeps
  @param times is the number off beeps we hear.
*/
void beep(int times) {
  for (int i = 0; i < times; i++) {
    digitalWrite(BUZZER, HIGH);
    delay(50);
    digitalWrite(BUZZER, LOW);
    delay(50);
  }
}


/**
  The function beeps
  @param times is the number off beeps we hear.
*/
void beepSOS() {
  for (int i = 0; i < 20; i++) {
    digitalWrite(BUZZER, HIGH);
    delay(200);
    digitalWrite(BUZZER, LOW);
    delay(200);
  }
}
/**
  The function setup all the basic needs for our programm
*/
void setup() {

#if DEBUG==1 && FUNC_TAGS==1
  Serial.begin(115200);
  Serial.println(F("***ComplexArduinoCode.setup - begin"));
#endif
  beep(2);    //A double beep to let the user know the system is up

  pinMode(LEFT_PUSH_BUTTON, INPUT);
  pinMode(BUZZER, OUTPUT);
  /*Setting up some of the peripheral files*/
  setupEEPROM();
  setupLcd();
  setupAirCondition();
  setupRelayLight();


  // Button uses the built-in pull up register.
  pinMode(BUTTON_PIN, INPUT_PULLUP);

  ButtonConfig* buttonConfig = button.getButtonConfig();
  buttonConfig->setEventHandler(handleEvent);
  buttonConfig->setFeature(ButtonConfig::kFeatureDoubleClick);
  buttonConfig->setFeature(
    ButtonConfig::kFeatureSuppressClickBeforeDoubleClick);
  buttonConfig->setFeature(ButtonConfig::kFeatureSuppressAfterClick);
  buttonConfig->setFeature(ButtonConfig::kFeatureSuppressAfterDoubleClick);


#if DEBUG==1 && FUNC_TAGS==1
  Serial.println(F("***ComplexArduinoCode.setup - end"));
#endif
}
/****************Main Code ********************************
  The next functions are the four functions coordinats with the Joystick
*/

void oneClick() {
#if DEBUG==1 && FUNC_TAGS==1
  Serial.println(F("***ComplexArduinoCode.up - begin"));
#endif
  //$1
#if DEBUG==1 && FUNC_TAGS==1
  Serial.println(F("***ComplexArduinoCode.up - end"));
#endif
}

void doubleClick() {
#if DEBUG==1 && FUNC_TAGS==1
  Serial.println(F("***ComplexArduinoCode.right - begin"));
#endif
  //$2
#if DEBUG==1 && FUNC_TAGS==1
  Serial.println(F("***ComplexArduinoCode.right - end"));
#endif
}


void loop()
{
  /*Here we deal with the setup button:
    this is the main idea:
    When the button val is high, start a loop (busy wait) -
    (we are assuming that if the user wants to get edit mode,
    he doesnt care about the programm not doing other stuff right now)
    you keep the while going if the following hppans:
    button is still pressed (HIGH) && there were less then 3 sec from the initial button pressed.

  */
  if (digitalRead(LEFT_PUSH_BUTTON) == 1) {
    lastTime = currentTime;
    while (millis() - lastTime < 3000 && digitalRead(LEFT_PUSH_BUTTON) == 1) {
    }
    //What is the reason we left the loop? if button is still pressed so its good, lets go into edit mode
    if (digitalRead(LEFT_PUSH_BUTTON) == 1) {
      writeLcd("SETUP MODE");
      beep(6);    //Beep 6 times to let the user know we are in edit mode
      setupMode = true; //Setting the setMode to true so the screen won't turn off during edit mode
      editCommand();
      writeLcd("SETUP End");
      setupMode = false;
    }
  }

  /*This code is turning off the screen if there was no action for more than @parameter LCD_DELAY_TIME*/
  currentTime = millis();
  if (currentTime - lastTime >= LCD_DELAY_TIME && !setupMode) {
    sleepLcd();
    //currentDirection = 'N';
  }

  // Should be called every 20ms or faster for the default debouncing time
  // of ~50ms.
  button.check();

}

// The event handler for the button.
void handleEvent(AceButton* /* button */, uint8_t eventType,
                 uint8_t /* buttonState */) {
  switch (eventType) {
    case AceButton::kEventClicked:
    case AceButton::kEventReleased:
      beep(2);
      writeLcd("Click");
      oneClick();

      break;
    case AceButton::kEventDoubleClicked:
      beep(4);
      writeLcd("Double Click");
      doubleClick();
      break;
  }
}




/*********************Constants*********************************/
#define IR_ON_SIZE 0
#define IR_ON_ADDRESS 2
#define IR_OFF_SIZE 512
#define IR_OFF_ADDRESS 514

/*********************Ports*********************************/

IRsend irsend;
int khz = 38; // 38kHz carrier frequency for the NEC protocol
int restoredIR_ArrayLength;
int savedIrONLength;
int savedIrOFFLength;
unsigned int* savedIrON;
unsigned int* savedIrOFF;

bool airConditionIsOn = false;
/**
    Setup all the needs
*/
void setupAirCondition() {
#if DEBUG==1
  Serial.println(F("Debugging mode in AirCondition:"));
#endif
  savedIrON = NULL;
  savedIrOFF = NULL;
  savedIrONLength = EEPROM.read(IR_ON_SIZE);
  savedIrOFFLength = EEPROM.read(IR_OFF_ADDRESS);
}


/**
    Print the result (second argument) as Pronto Hex on the Stream supplied as argument.
    @param state tells us whether we wnat to turn ON (state=1) or OFF (state=2)
*/
void turnAC() {
  int state = -1;
#if DEBUG==1 && FUNC_TAGS==1
  Serial.println(F("***AirConditionHelper.turnAC - begin"));
#endif
#if DEBUG==1
  printEeprom();
#endif
  /*this part is for 2 actions in one click turn ac on if now its on and opposite*/
  if (airConditionIsOn) {
    state = 0;
    airConditionIsOn = false;
  } else {
    state = 1;
    airConditionIsOn = true;
  }

  //temp variables
  unsigned int * arrPointer ;
  int arrSize;
  int dataAddressInMemory;

  if (state == 1) { //ON
    arrPointer = savedIrON;
    arrSize = savedIrONLength;
    dataAddressInMemory = IR_ON_ADDRESS;
  } else {   //OFF
    arrPointer = savedIrOFF;
    arrSize = savedIrOFFLength;
    dataAddressInMemory = IR_OFF_ADDRESS;
  }


  //In case of a new ir Code we need to get its length and to read the memory with the data
  if (arrPointer == NULL) {
    arrPointer = new unsigned int[arrSize];


    //Now we need the original pointers to hold the right adress
    if (state == 1) { //ON
      savedIrON = arrPointer ;
    } else {   //OFF
      savedIrOFF = arrPointer;
    }

    //Reading the data into our allocated array - arrPointer
    readIntArray(dataAddressInMemory, arrPointer, arrSize);
  }
#if DEBUG==1
  if (state == 1) {
    Serial.print(F("savedIrON ["));
  } else {
    Serial.print(F("savedIrOFF ["));
  }
  Serial.print(arrSize);
  Serial.println(F("] = {"));
  for (int i = 0; i < arrSize; i++) {
    Serial.print(arrPointer[i]);
    Serial.print(",");
  }
  Serial.println("}");
#endif
  irsend.sendRaw(arrPointer, arrSize, khz); // Note the approach used to automatically calculate the size of the array.


  arrPointer = NULL;
  arrSize = -1;
  dataAddressInMemory = -1;

#if DEBUG==1 && FUNC_TAGS==1
  Serial.println(F("***AirConditionHelper.turnAC - end"));
#endif
}

void editCommand() {
#if DEBUG==1 && FUNC_TAGS==1
  Serial.println(F("***AirConditionHelper.editCommand - begin"));
#endif


  writeLcd(F("R-on L - off"));

  do {
    leftButtonVal = digitalRead(LEFT_PUSH_BUTTON);
    rightButtonVal = digitalRead(RIGHT_PUSH_BUTTON);
  }
  while (leftButtonVal == 0 && rightButtonVal == 0);
  beep(2);
  if (rightButtonVal == 1) {
    writeLcd("Right - on");
    delete savedIrON;
    savedIrON = NULL;
  } else {
    writeLcd("Left - off");
    delete savedIrOFF;
    savedIrOFF = NULL;
  }


#if DEBUG==1
  Serial.println(F("The chozen dir to edit is:"));
  if (rightButtonVal == 1) {
    Serial.println(F("Right side - On - command"));
  } else {
    Serial.println(F("Left - Off - command"));
  }
#endif

  delay(2000);
  setupRec();
  if (rightButtonVal == 1) {
    recordIr(1);
  } else {
    recordIr(0);
  }
#if DEBUG==1 && FUNC_TAGS==1
  Serial.println(F("***AirConditionHelper.editCommand - end"));
#endif
}




#include <EEPROM.h>


#define EEPROM_SIZE 1024


void setupEEPROM() {
#if DEBUG==1 && FUNC_TAGS==1
  Serial.println(F("***EEPROMHelper.setup - begin"));
#endif

  if (EEPROM.read(IR_ON_SIZE) == 0 && EEPROM.read(IR_OFF_SIZE) == 0) {
    setAllMemTo(0);
  }

#if DEBUG==1 && FUNC_TAGS==1
  Serial.println(F("***EEPROMHelper.setup - end"));
#endif
}
/**
    Read data from EEprom to a given array a.k.a. numbers
    @param address is the adress to begin reading from
    @numbers is the given array we are filling
    @param arraySize is the length od the array
*/
void readIntArray(int address, unsigned int numbers[], int arraySize)
{
#if DEBUG==1 && FUNC_TAGS==1
  Serial.println(F("***EEPROMHelper.readIntArray - begin"));
#endif
  int addressIndex = address;
  for (int i = 0; i < arraySize; i++)
  {
    (EEPROM.get(addressIndex, numbers[i]));
    addressIndex += sizeof(int);
  }
#if DEBUG==1 && FUNC_TAGS==1
  Serial.println(F("***EEPROMHelper.readIntArray - end"));
#endif
}

/**
    Wrote data to EEprom from a given array a.k.a. numbers
    @param address is the adress to begin write to
    @numbers is the given array to write the disk from it
    @param arraySize is the length od the array
*/
void writeIntArray(int address, unsigned int numbers[], int arraySize) {
#if DEBUG==1 && FUNC_TAGS==1
  Serial.println(F("***EEPROMHelper.writeIntArray - begin"));
#endif
  int addressIndex = address;
  for (int i = 0; i < arraySize; i++)
  {
    EEPROM.put(addressIndex, numbers[i]);
    addressIndex += sizeof(int);
  }
#if DEBUG==1 && FUNC_TAGS==1
  Serial.println(F("***EEPROMHelper.writeIntArray - end"));
#endif
}

/**
  Prints The EEPROM content in aorgenized way in the serial
*/
void printEeprom() {

#if DEBUG==1 && FUNC_TAGS==1
  Serial.println(F("***EEPROMHelper.printEeprom - begin"));
#endif
  int bytesPerRow = 32;
  int tempNum;
  Serial.print(F("\n -----------------------------------------------------"));
  Serial.println(F("EEPROM content:-------------------------------------------------------"));

  for (int i = 0; i < EEPROM_SIZE; i++) {

    //Printing the rows numbers
    if (i % bytesPerRow == 0) {
      Serial.print(F("\n  ["));
      printNumbersCenterd((i / bytesPerRow), 3);
      Serial.print(F("]:     "));
    }

    EEPROM.get(i, tempNum);
    printNumbersCenterd(tempNum, 4);
    Serial.print(F(" | "));
    i++;

  }
  Serial.print(F("\n\n"));

#if DEBUG==1 && FUNC_TAGS==1
  Serial.println(F("***EEPROMHelper.printEeprom - end"));
#endif
}

/**
    Setting all the EEPROM memory to be zero (This is for Debugging uses)

*/
void setAllMemTo(int num) {
#if DEBUG==1 && FUNC_TAGS==1
  Serial.println(F("***EEPROMHelper.setMemToZero - begin"));
#endif
  for (int i = 0; i < 1024; i++) {
    EEPROM.write(i, num);
  }
#if DEBUG==1 && FUNC_TAGS==1
  Serial.println(F("***EEPROMHelper.setMemToZero - end"));
#endif
}

/*this 2 function is only for printing the EEPROM nicely*/
void printNumbersCenterd(int number, int len) {

  int spaces = len - countNumberLength(number);
  for (int i = 0; i < spaces / 2; i++) {
    Serial.print(F(" "));
  }

  Serial.print(number);

  for (int i = 0; i < spaces / 2; i++) {
    Serial.print(F(" "));
  }
  if (spaces % 2 != 0) {
    Serial.print(F(" "));
  }
}
/*this function is only for printing the EEPROM nicely*/
int countNumberLength(int number) {
  int temp, counter = 0;
  number = number / 10;
  counter++;
  while (number > 0) {
    number = number / 10;
    counter++;
  }
  return counter;
}





bool lightIsOn = false;
/**
    Setup all the needs
*/
void setupRelayLight() {
#if DEBUG==1 && FUNC_TAGS==1
  Serial.println(F("***RelayLightHelper.setupRelayLight - begin"));
#endif

  pinMode(RELAY_LIGHT, OUTPUT);
#if DEBUG==1 && FUNC_TAGS==1
  Serial.println(F("***RelayLightHelper.setupRelayLight - end"));
#endif
}


/**

*/
void turnRelayLight() {
#if DEBUG==1 && FUNC_TAGS==1
  Serial.println(F("***RelayLightHelper.turnRelayLight - begin"));
#endif
  if (lightIsOn) {
    digitalWrite(RELAY_LIGHT, LOW);
    lightIsOn = false;
  } else {
    digitalWrite(RELAY_LIGHT, HIGH);
    lightIsOn = true;
  }


  pinMode(RELAY_LIGHT, OUTPUT);
#if DEBUG==1 && FUNC_TAGS==1
  Serial.println(F("***RelayLightHelper.turnRelayLight - end"));
#endif
}





#include <IRremote.h>

#define IR_RECEIVE_PIN 11

IRrecv irrecv(IR_RECEIVE_PIN);

//+=============================================================================
// Configure the Arduino
//
void setupRec() {
#if DEBUG==1 && FUNC_TAGS==1
  Serial.println(F("***acReciverHelper.setupRec - begin"));
#endif


  //#if DEBUG==1
  //  // Just to know which program is running on my Arduino
  //  Serial.println(F("START " __FILE__ " from " __DATE__));
  //#endif

  irrecv.enableIRIn();  // Start the receiver

#if DEBUG==1
  Serial.print(F("Ready to receive IR signals at pin "));
  Serial.println(IR_RECEIVE_PIN);
#endif

#if DEBUG==1 && FUNC_TAGS==1
  Serial.println(F("***acReciverHelper.setupRec - end"));
#endif
}

//+=============================================================================
// Dump out the decode_results structure.
//
void dumpCode(decode_results *results) {
  // Start declaration

#if DEBUG==1
  Serial.print("unsigned int  ");          // variable type
  Serial.print("rawData[");                // array name
  Serial.print(results->rawlen - 1, DEC);  // array size
  Serial.print("] = {");                   // Start declaration


  // Dump data
  for (unsigned int i = 1; i < results->rawlen; i++) {
    Serial.print(results->rawbuf[i] * MICROS_PER_TICK, DEC);
    if (i < results->rawlen - 1)
      Serial.print(","); // ',' not needed on last one
    if (!(i & 1))
      Serial.print(" ");
  }

  // End declaration
  Serial.println("};");  //
#endif
}

//+=============================================================================
// The repeating section of the code
//
void recordIr(int state) {    //state is the ir command we shopuld change 1 on 0 off
#if DEBUG==1
  Serial.println(F("***acReciveHelper.recordIr-start"));
#endif

  writeLcd("click the remote");
  decode_results results;        // Somewhere to store the results
  boolean isRecieving = true;
  while (isRecieving) {
    if (irrecv.decode(&results)) { // Grab an IR code `
      dumpCode(&results);           // Output the results as source code
      beep(8);
      writeLcd(F("code was recieved"));
      delay(4000);
      irrecv.disableIRIn();
      isRecieving = false;
    }
  }
#if DEBUG==1
  printEeprom();
#endif
  /*TODO:put this at the EEPROM helper*/
  int addressIndex;
  if (state == 1) {
    savedIrONLength = results.rawlen - 1; //Weird stuff in the first cell
    addressIndex = IR_ON_ADDRESS;
    EEPROM.write(IR_ON_SIZE, savedIrONLength);
  } else {
    savedIrOFFLength = results.rawlen - 1; //Weird stuff in the first cell
    addressIndex = IR_OFF_ADDRESS;
    EEPROM.write(IR_OFF_SIZE, savedIrOFFLength);
  }

  unsigned int temp;
  for (unsigned int i = 1; i < results.rawlen; i++)
  {
    temp = results.rawbuf[i] * MICROS_PER_TICK;
    EEPROM.put(addressIndex, temp);
    addressIndex += sizeof(int);
  }

#if DEBUG==1
  printEeprom();
#endif
#if DEBUG==1
  Serial.println(F("***acReciveHelper.recordIr-end"));
#endif
}




#include <Wire.h>
#include <LiquidCrystal_I2C.h>
LiquidCrystal_I2C lcd(0x27, 20, 4);


void setupLcd() {
  lcd.init();       // initialize the lcd
  lcd.backlight();  //Turn the lcd light - ON
  lcd.clear();      //Clear The text on the lcd
  lcd.print(F("Welcome to"));
  lcd.setCursor(0, 1);
  lcd.print(F("Milbat #PATIENT_NAME"));
}

void writeLcd(String text) {
  //todo - deal with strings longer than 16 chars
  lcd.backlight();
  lcd.setCursor(0, 0);
  lcd.clear();
  lcd.print(text);
}
void sleepLcd() {
  lcd.clear();
  lcd.noBacklight();
}

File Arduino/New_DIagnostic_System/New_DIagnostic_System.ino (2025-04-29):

#include <SoftwareSerial.h>

#define BAUDRATE 9600
#define DEBUG 1
SoftwareSerial blue(2, 3); // bluetooth module connected here (3 is RX and 2 is TX)

#define X_PIN A1                   //Naming all the used PINs
#define Y_PIN A0
#define DUPS 5   //Data units per second
#define POTENTIOMETER_PIN A2
#define KNOCK_PIN 10
#define LED_PIN 13
#define DELAY 300

//Declaring all the vars
int xData = 0;
int yData = 0;
int knockData = 0;
int resistanceData = 0;
char menu = 0;
String input = "";


void setup() {
  pinMode(KNOCK_PIN, INPUT);
  pinMode(LED_PIN, OUTPUT);         //Determining the PINs way of work
  pinMode(X_PIN, INPUT);
  pinMode(Y_PIN, INPUT);
  pinMode(POTENTIOMETER_PIN, INPUT);

  //For debugging modes only
#if DEBUG==1
  Serial.begin(9600);                //Beginning the connection with the BT and the serial
#endif
  blue.begin(BAUDRATE);                  //TODO - We need to check if it is possible to change the baudrate to something faster
}

//Actual loop running
void loop() {
  if (blue.available() > 0) {
    input = blue.readString();       // reading the data received from the bluetooth module

    /*This is if is for checking that the command from BT was to switch sensor*/
    if (input[0] == 'S') {
      menu = input[1];
    }
#if DEBUG==1
    Serial.println("The incoming input is: " + input);
    Serial.print("The chosen Sensor is: ");
    Serial.println(menu);
#endif
  }
  switch (menu) {
    case '1'://joystick sensor
      //Serial.print("Joystick");
      // read the value at analog input
      xData = analogRead(X_PIN);   //TODO  - mapping the analog value to 8/16/32 bit https://www.arduino.cc/reference/en/language/functions/math/map/
      yData = analogRead(Y_PIN);

      //This part should take care of the data rate DUPS is the "Data Unit Per Second"
      delay(DELAY);// / DUPS ); // todo - substract the time it takes from last print until here




      /*an old version just for checking*/

      blue.print("");
      blue.print(xData);
      blue.print("#");
      blue.print(yData);
      blue.print("#");

      //      blue.print(millis() / 1000);
      //      blue.print("(");
      //      blue.print(xData);
      //      blue.print(",");
      //      blue.print(yData);
      //      blue.print(")\n");
#if DEBUG==1
      Serial.print("(");
      Serial.print(xData);
      Serial.print(",");
      Serial.print(yData);
      Serial.print(")\n");
#endif
      break;
    case '2'://binary sensor
      knockData = digitalRead(KNOCK_PIN);
      delay(DELAY);// / DUPS ); // todo - substract the time it takes from last print until here
      switch (knockData)
      {
        case HIGH: digitalWrite(LED_PIN, HIGH);   // Led\lamp is on
          break;
        case LOW: digitalWrite(LED_PIN, LOW);    // Led\lamp is off
          break;
        default : break;
      }
#if DEBUG==1
      Serial.print("Knock value is ");
      Serial.println(knockData);
#endif
      //blue.print("Knock value is ");
      blue.print("#");
      blue.print(knockData);
      break;
    case '3'://analog sensor
      resistanceData = analogRead(POTENTIOMETER_PIN);
#if DEBUG==1
      Serial.print("resistance value is ");
      Serial.println(resistanceData);
#endif
      blue.print("#");
      blue.print(resistanceData);
      delay(DELAY);// / DUPS ); // todo - substract the time it takes from last print until here
      break;
    case '9':
      //Serial.print("Joystick");
      // read the value at analog input
      xData = analogRead(X_PIN);   //TODO  - mapping the analog value to 8/16/32 bit https://www.arduino.cc/reference/en/language/functions/math/map/
      yData = analogRead(Y_PIN);

      //This part should take care of the data rate DUPS is the "Data Unit Per Second"
      delay(500);// 1000 / DUPS ); // todo - substract the time it takes from last print until here

      blue.print(millis() / 1000);
      blue.print("(");
      blue.print(xData);
      blue.print(",");
      blue.print(yData);
      blue.print(")\n");
#if DEBUG==1
      Serial.print("(");
      Serial.print(xData);
      Serial.print(",");
      Serial.print(yData);
      Serial.print(")\n");
#endif
      break;
    default:
      break;
  }

}

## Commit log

2020-05-25 add new activity(sensor)
2020-05-26 implement sensor1(joystick)
2020-05-31 update layout of sensor1(include add DynamicSquareLayout class) + add target + add win voice + add end of screen warning
2020-06-07 new activity wad made with a tryouts for parsing. works with the newest arduino code
2020-10-13 Sending arduino file is working!! Adding menus Arranging some of the layouts
2020-10-27 Advanced Arduino code generator+debug mode
2020-10-28 New visual for sensors Results Activity
2020-10-28 Lines for analog sensor
2020-11-25 collect data in analog sensor
2020-12-01 Fixing a problem in the edit
    [BlankButton.ino, BlankJoystick.ino, Form.java]
2020-12-01 button out of Oncreate
2020-12-01 fix collect data in analog sensor
2025-04-29 Adding Arduino codes and documents
    [Diagnostic_System_Sketch_1.0.fzz, Helping_System_Sketch.fzz, Helping_System_Sketch_2.0.fzz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]
